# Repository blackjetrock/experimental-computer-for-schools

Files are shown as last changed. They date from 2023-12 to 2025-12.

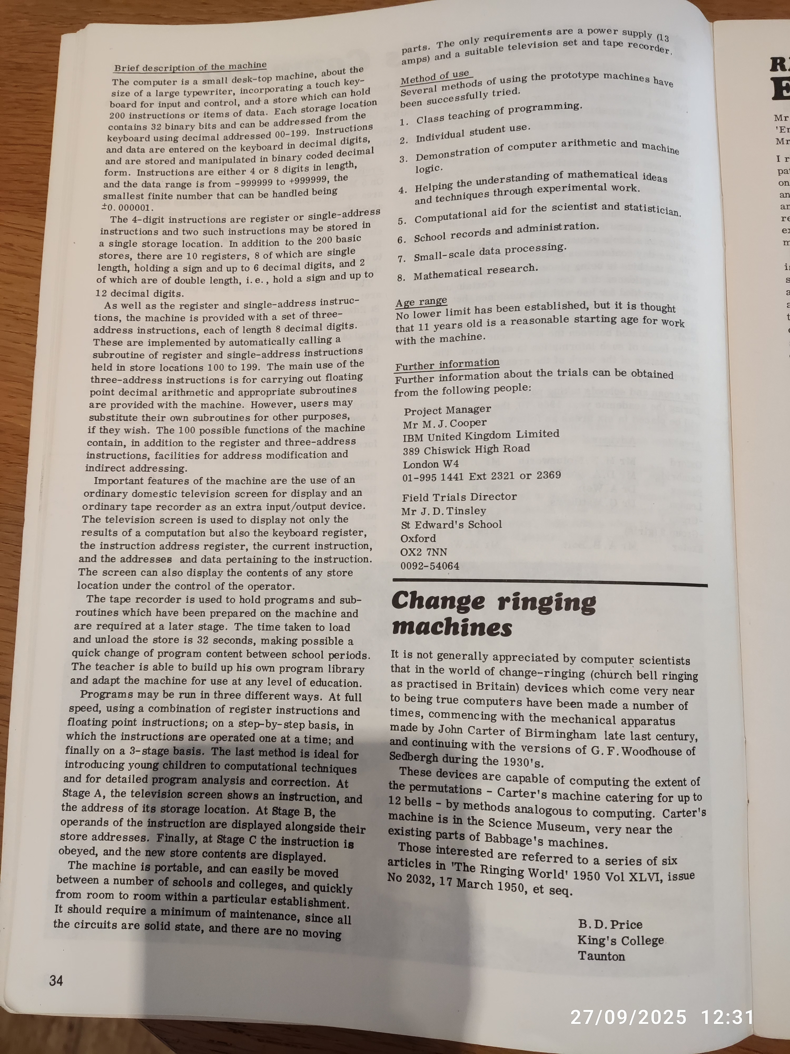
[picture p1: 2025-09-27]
Documentation/1000038514.jpg

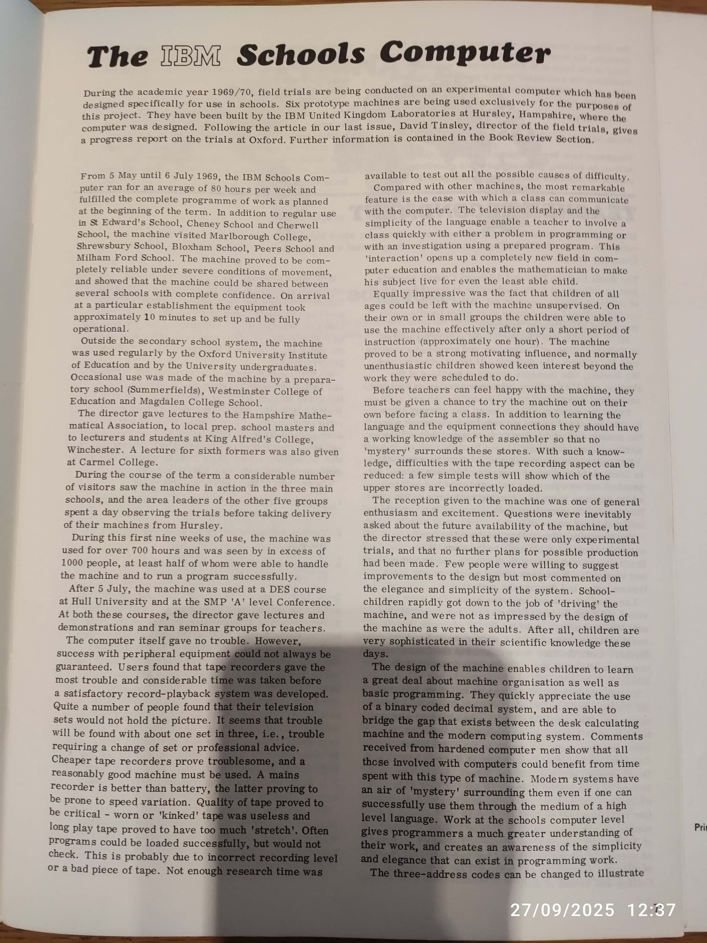
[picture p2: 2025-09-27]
Documentation/1000038515.jpg

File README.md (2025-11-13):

# IBM Experimental Computer for Schools

The schools computer project ran from 1966 to 1970 and was an experimental machine that was never sold, although several were made and were used in schools in the UK. One machine was used for ten years before it failed. It was designed to be used in schools to teach the basics of computer design and programming. The hardware was based on the same components that the IBM system 360 used. The computer was programmed in machine code, and unlike modern machines the machine code is BCD based, not binary. There are 'extracodes' in the system that are analogous to subroutines, these provided floating point arithmetic at the machine code level. The extracodes could be replaced with user code if desired, and provide a completely different set of functions.

As far as I an tell this machine was the first machine purpose built for education. there are lots of examples of computers being used to teach fundamentals of programming and computer architecture, but they are general purpose machines in educational situations, this is the earliest machine designed for the purpose I can find.

It also seems to be the first machine to use a domestic television as a display, and the first to use a tape recorder to store and load code.

This is a simulation of the machine. It can run code written for the original machine.

<h2>Update Nov 2025</h2>
More information about the School's Computer has been found. This is a large collection of documents, programs for the machine, and information about the machine. One item that is of particular interest is the original extracode for the machine. In fact, there are about four different extracodes for the machine. There is also a draft of a 'Second Course on the School's Computer', which provides more detailed information abou thow the machine works. This information has been kept (for over 50 years) by one of the pupils (thanks Tony) that used the machine when it was trialled. Thanks to him, the original extracode can be used by the replica.

<h1>USB</h1>
USB can be used to interact with the simulator. It just requires a Pico. You can run a simulator with just a Pico, the PCB isn't necessary. If you have a Pico W then you can access over WiFi as well.
A command line interface (CLI) is available on the USB connection, this requires a terminal emulator program such as minicom. Using the interface you can:

* Drive keys as if they came from the keyboard
* See a representation of the display.
* Run tests that check the simulation is running as required.
* Load programs from the document 'A First Course on the School's Computer'
* Run programs
* Examine the store
* Examine the machine state
* Load and store machine state from and to the SD card

<h1>Tests</h1>

There is a set of tests built in to the firmware that can be run to check th eoperation of the machine.
The tests are run using the '=' menu option on the USB CLI. They take quite a while to run and once finished the '@' menu option can be used to display the result. If a test is successful then 'Passed' is displayed. If it failed the 'Failed' is displayed, along with the expected and calculated results. It is possible to run a single test using the '[' command to load the test (after entering the test number with z nn ESC), then '+' to run it. The resut is displayed using '@'.

The tests are currently set up to test the standard extracode. This means the results are tailored to that extracode. As an instruction like 70202122 can perform any function, depending on th eextracode in 100..199 this will have to change.  I allowed the original extracode to be tested, though.

<h1>PCB</h1>

There is a PCB that has a Pico mounted on it. This photo shows the PCB with a Pico W attached. The simulator code can be built with or without WiFi support.

IMG_4442p1

This has a 0.96" OLED display that shows the same information as the original machine displayed on a domestic TV.



 There is an SD card for storage and a keyboard made from tactile switches, in the same layout as the original machines. The operation is very similar to the original, some differences have been made to key operations to enable use of the SD card. the original machines used audio cassettes for data storage.
 

 The Pico can be a PicoW, in which case a WiFi access point is generated.

<h1>Wifi Version</h1>
This version has a USB interface, and a Wifi interface (it generates a hot spot). The USB interface still works. The Wifi page shows the display and allows control from a web page. This version of the code runs on a Pico W and generates its own access point.

Screenshot from 2024-08-30 09-09-44

If building for a Pico W then use this command line:

<code>cmake -DPICO_BOARD=pico_w -DWIFI_SSID="Schools" -DWIFI_PASSWORD="password" ..</code>

to initialise the build directory in the 

<code>firmware/escw</code>

directory. Then 

<code>make</code>

as usual.
To build the non-Wifi version, 

<code>cmake ..</code>

in the 

<code>experimental_schools_computer/build</code>

directory and then make as usual.

<h1>Half Scale Replica</h1>

IMG_20240827_103823604_HDR

The half scale replica is constructed of similar materials to the original, and runs the same code as the small PCB version, with some modifications for the different display and keyboard. The display is a large LCD instead of a small OLED and a touch keyboard is used instead of tactile switches. The case is aluminium which has been powder coated, the keyboard surround is a 3D printed resin part. The original machine also used a plastic surround, this is probably because a metal surround would interfere with the touch keyboard. And, yes, that is the original machine next to the replica.

<h1>Assembler</h1>
I have created an assembler that assembles instructions expressed in the verbose comments seen in the documents available for this computer. 

<h1>Documents</h1>

<h2>A First Course on the Schools's Computer</h2>
This is a document that provided a course on programming the computer, there are only three known paper copies of this document (in two revisions), but it has been
copied and put together into a PDF document. It has several programs written for the machine, which are the only ones I know of from the time
when the machine was trialled. These programs almost exclusively use the extracodes for the programs, not the half-word basic instructions which must have been used to implement
the extracodes themselves in the store from address 100 to 199. 

<h2>A Draft Second Course on the School's Computer</h2>
This is a short typewritten document that is the beginning of a second course on the machine. It expains some of the instructions that weren't detailed in the first course. It appears that the School's Computer project was cancelled before this course could be completed.

<h2>Experimental Computer for Schools</h2>
Describes the hardware and code design of the machine. This is a technical description of the machine, and contains no program listings at all.

<h2>Flowcharts</h2>
This is a four page document that has flowcharts and programs for log<sub>b</sub>N and b<sup>L</sup>.
The programs use an extracode that isn't in the standard set, which is a square root instruction. The instruction also has a jump and the jump part is used in the programs without use of the square root operation. Together with the first course on the school's computer these are the only known programs for the computer from the time whenit was being develped and trialled.

<h2>Extracode</h2>
The extracode of the machine is sort of equivalent to the ROM in an 80's home computer, but there are significant differences. In its original form it provided some floating point instructions, and so compared to a ROM it provides a small number of features. Unlike a ROM, though, it was intended that people altered or even completely rewrote the extracode, and that did happen. Several different extracodes exist, for various reasons, they are listed below.
There is now framework for running extracode, so the original extracodes can be executed. It's not quite correct at the moment as the A,B and C stage keys step through the extracode instructions, on th eoriginal they stepped through the 'top level' three address instruction. 

<h3>Standard Floating Point</h3>
This is the extracode that provoides the instructions used in the 'First Course'. It provides simple floatoing point operations, these are listed in the 'Experimental Computer fo School's' document.

<h3>BASIC</h3>
this extracode is supplied in the form of a set of changes to be made to the standard extracode. It provides insrtuctiins that mirror a few BASIC commands. A BASIC program can be written (by hand, on paper) and then translated to extracdoe instructions, these can be entered into the school's computer and executed. There are some examples of this isn the documents.

<h3>Pseudo Random Number Generator</h3>

<h3>Square Root</h3>
This extracode provides a square root instruction. It replaced one of the standard extracodes and was used for any program that needed a square root. It is mentioned in some of the first documents I found, and a listing is in the latest documents.

<h3>Noughts and Crosses</h3>
This game was written by Tony Malins around 1970 and was such a large program that it used the extracode space as well as the user space.

<h1>References</h1>

The thread on 'retrocomputingforum.com' where Tony presents his documents and programs:
https://retrocomputingforum.com/t/rare-ibm-schools-computer-1969/5209/51

A photo of the schools computer in a classroom in the 60s:
https://www.stedwardsarchives.org/PDFViewer/web/viewer.html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

https://www.stedwardsarchives.org/PDFViewer/web/viewer.html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

https://ibmhursleymuseum.info/hardware-data-detail.asp?id1=140

https://news.ycombinator.com/item?id=36112633

https://www.stedwardsarchives.org/PDFViewer/web/viewer.html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

https://www.stedwardsarchives.org/PDFViewer/web/viewer.html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

https://www.stedwardsarchives.org/PDFViewer/web/viewer.html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

https://www.stedwardsarchives.org/PDFViewer/web/viewer.html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

https://www.stedwardsoxford.org/obituary/david-tinsley/

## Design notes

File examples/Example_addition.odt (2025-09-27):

Experimental Computer for Schools

Example

This example adds two numbers by loading the store with the values and then using a ‘Keyboard Reset’ to enter an instruction that adds the contents of two locations in the store, putting the result in a third location.

With the ESC replica on:

Press ‘Normal reset’

Press ‘1’

Press ‘2’

Press ‘Load addr’

Press ‘4’

Press ‘5’

Press ‘point’

Press ‘3’

Press ‘Load store’

Press ‘Incr addr’

Press ‘1’

Press ‘3’

Press ‘point’

Press ‘9’

Press ‘Load store’

The two values to add are now in store locations 11 and 12.

Now, enter and run the addition instruction:

Press ‘Ki Reset’

Type the number: ‘70101112’

This is the instruction code.

Press ‘A’

The first stage of the instruction is processed (store addresses are shown)

Press ‘B’

The second stage of the instruction has been processed. The contents of the store locations are shown. These are the two values that will be added.

Press ‘C’

The instruction is processed to completion. The sum can be seen as the contents of store location 10:

Press ‘1’

Press ‘0’

Press ‘Load addr’

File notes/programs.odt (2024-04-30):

Experimental School’s Computer

Programs

This document is a collection of programs for the experimental school’s computer from around 1970. There are not very many programs known, these all come from the first course on the school’s computer.

A Program to Compute the Surface Area and Volume of a Sphere.

Address | Contents | Comments
0 | | Spare
1 | | Spare
2 | r
3 | a
4 | b
5 | 3.14159
6 | 4
7 | 3
8 | | Spare
9 | | Spare
10 | 7802 0507 | Input r; display 3.14159 and 3
11 | 7203 0202 | a ← r x r
12 | 7203 0305 | a ← a x 3.14159
13 | 7203 0306 | a ← a x 4
14 | 7204 0302 | b ← a x r
15 | 7304 0407 | b ← b ÷ 3
16 | 7902 0304 | Display r, a and b
17
18
19
20

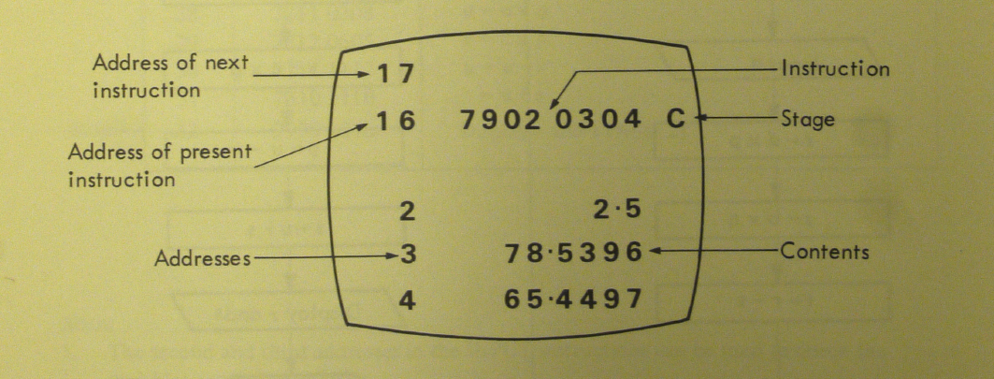
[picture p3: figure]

SOLUTION OF TWO LINEAR SIMULTANEOUS EQUATIONS

Address | Contents | Comments
0 | | Spare
1 | | Spare
2 | | Spare
3 | a
4 | b
5 | p
6 | c
7 | d
8 | q
9 | r
10 | s
11 | u
12 | v
13
14
15 | 7803 0303 | Input a
16 | 7804 0303 | Input b
17 | 7805 0403 | Input p
18 | 7806 0504 | Input c
19 | 7807 0605 | Input d
20 | 7808 0706 | Input q
21 | 7209 0705 | r ← d x p
22 | 7210 0408 | s ← b x q
23 | 7109 0910 | r ← r - s
24 | 7210 0307 | s ← a x d
25 | 7211 0406 | u ← s - u
26 | 7110 1011 | s ← s – u
27 | 7309 0910 | r ← r ÷ s
28 | 7211 0308 | u ←a x q
29 | 7212 0605 | v ← c x p
30 | 7111 1112 | u ← u - v
31 | 7310 1110 | s ← u ÷ s
32 | 7909 1010 | Display r and s; stop

Experimental School’s Computer Programs

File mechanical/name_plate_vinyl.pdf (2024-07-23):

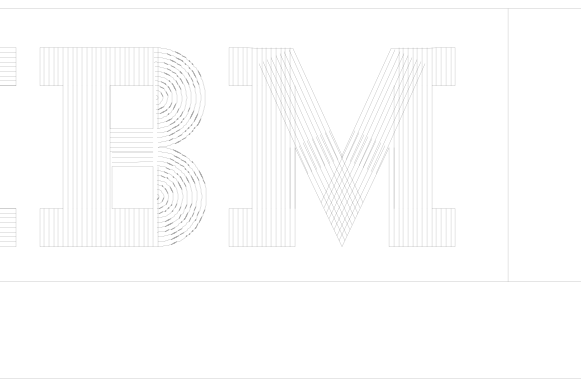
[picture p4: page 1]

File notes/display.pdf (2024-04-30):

Experimental School’s Computer Display Notes

Experimental Schools Computer Display

The TV display on the experimental school’s computer shows various pieces of information, at various times during the execution of programs and instructions. The documentation of the machine, which is limited, has some examples of the display. This document is an attempt to list these displays and the information they contain, link that to the events that caused the display and hopefully build up the rules that the machine uses to put information onto the display. This can then be coded in the simulation to give the user a display that is as useful as the original and also hopefully close to the original displays.

The display is 15 characters wide by six lines.

Experimental School’s Computer Display Notes

## Sequence 1

After resetting

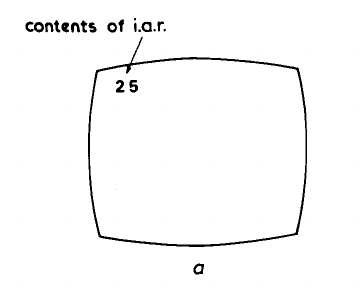
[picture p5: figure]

After keying in address

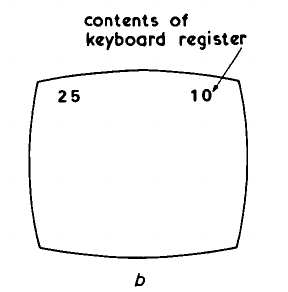
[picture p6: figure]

Experimental School’s Computer Display Notes

Experimental School’s Computer Display Notes

After touching LOAD ADDR key

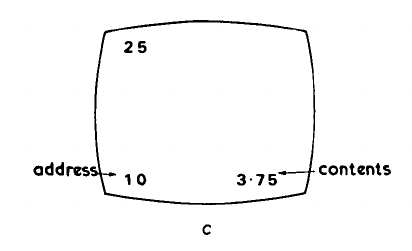
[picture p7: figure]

After keying in number to be loaded

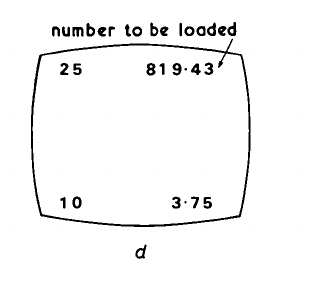
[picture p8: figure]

After touching LOAD STORE key

Experimental School’s Computer Display Notes

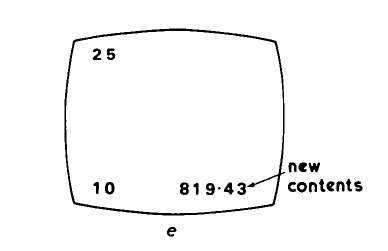
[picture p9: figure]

## Sequence 2

After keying in address of first instruction in program

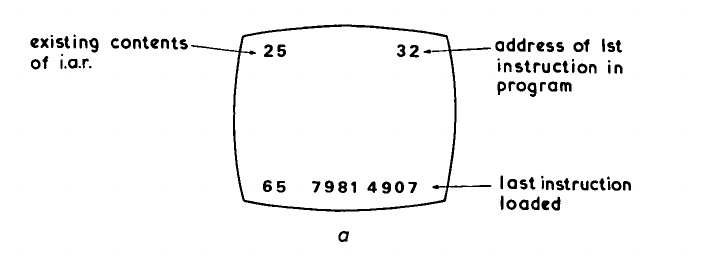
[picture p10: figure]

After touching LOAD IAR key

Experimental School’s Computer Display Notes

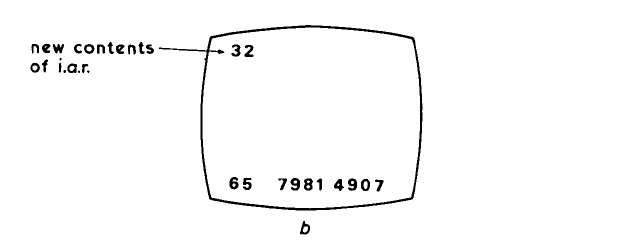
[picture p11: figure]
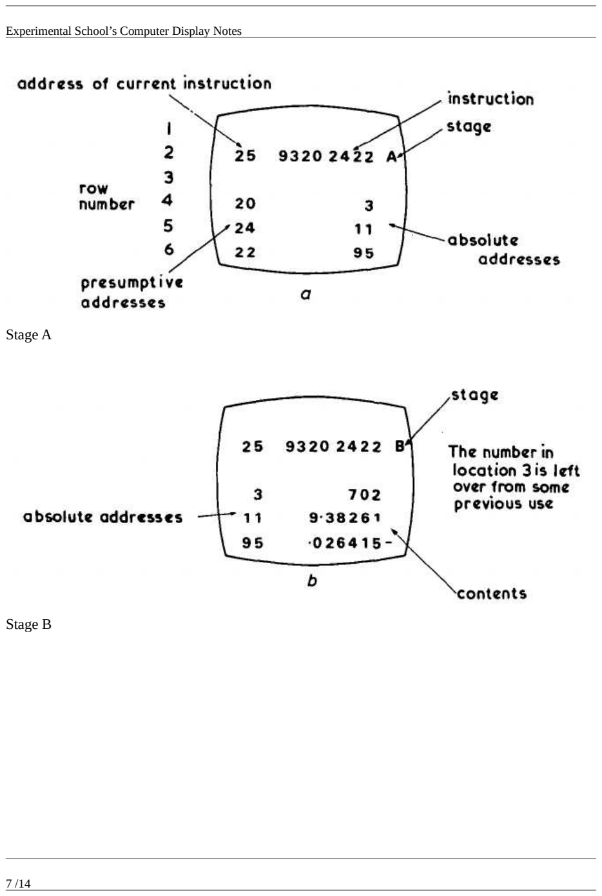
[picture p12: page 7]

Experimental School’s Computer Display Notes

Stage A

Stage B

Experimental School’s Computer Display Notes

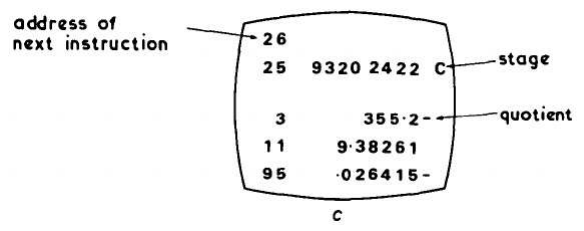
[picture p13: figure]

Stage C

Experimental School’s Computer Display Notes

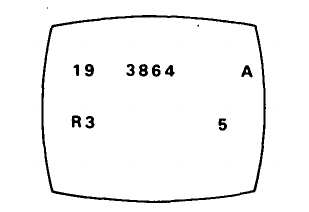
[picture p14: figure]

Single-address instruction with relative addressing

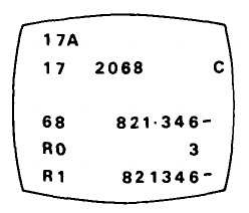
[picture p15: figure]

Single-address READ STORE instruction

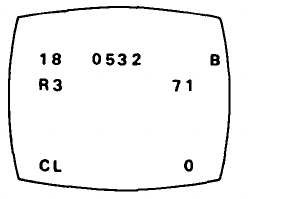
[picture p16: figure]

Experimental School’s Computer Display Notes

TEST instruction

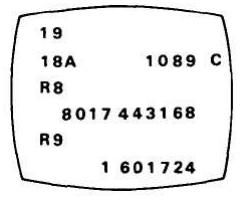
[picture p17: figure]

Adding contents of two double-length registers

Experimental School’s Computer Display Notes

From these screen layouts it appears that the top two lines of the display are in a fixed format, with the IAR, the address of the next instruction and the keyboard register contents displayed as the registers have values entered in them. There is also a display of the IAR flag that shows an ‘A’ when the instruction in the lower 4 digits is being referenced. The instruction processing stage (A,B, or C0 is also displayed.

The lower 4 lines, though, seem to be more free-form, with data displayed as instructions are processed. These lines will have data displayed as instructions are processed.

The character set is quite complete, the full ASCII set is available to the simulation, so that will be used. A small OLED display on the PCB is used to recreate the TV display, there is also a Usb CLI that has moire extensive displays, for instance the entire store can be displayed.

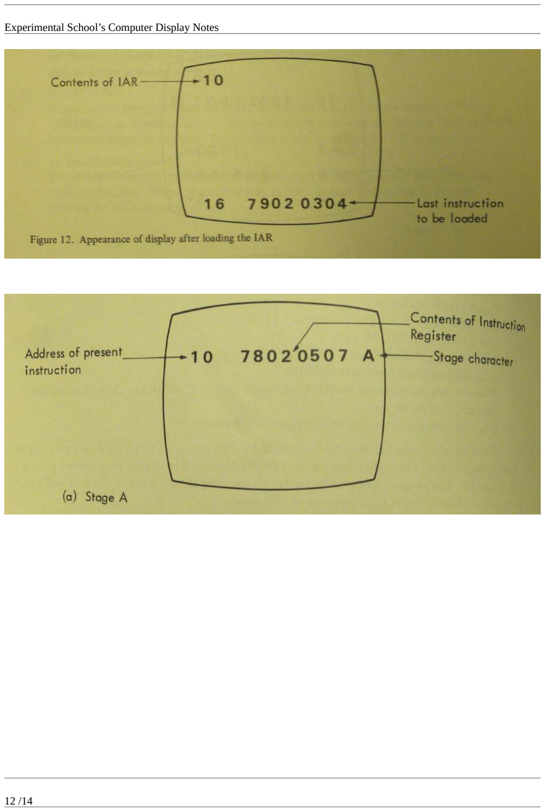
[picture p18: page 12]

Experimental School’s Computer Display Notes

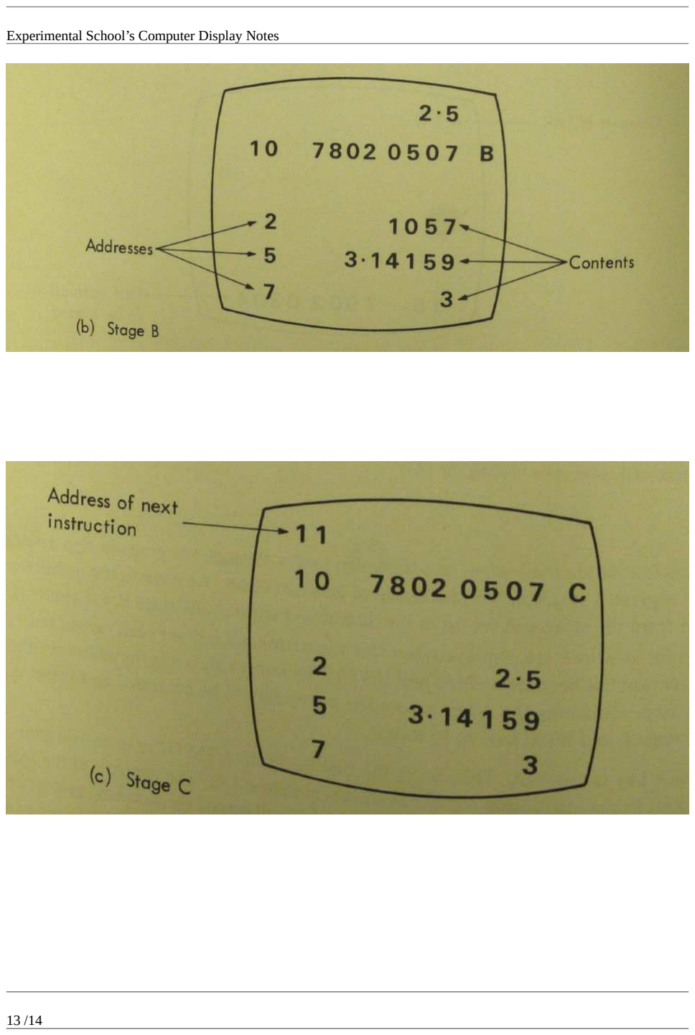
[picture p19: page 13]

Experimental School’s Computer Display Notes

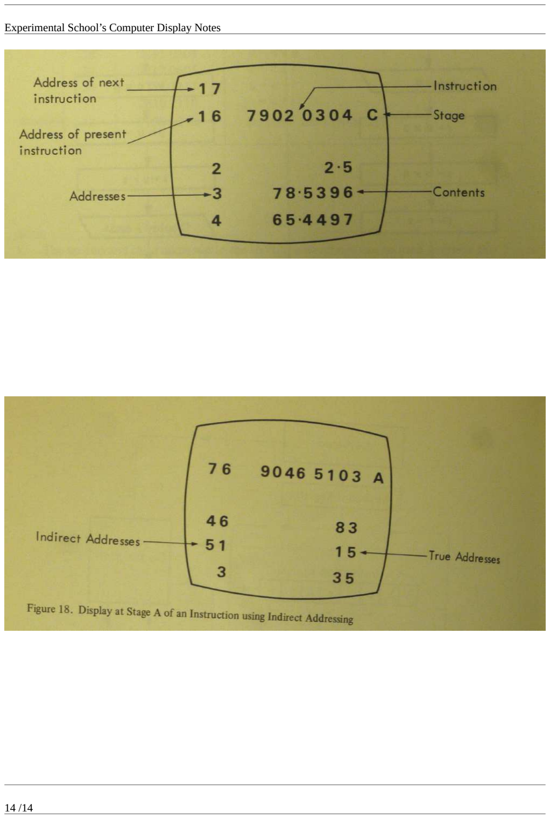
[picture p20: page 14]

Experimental School’s Computer Display Notes

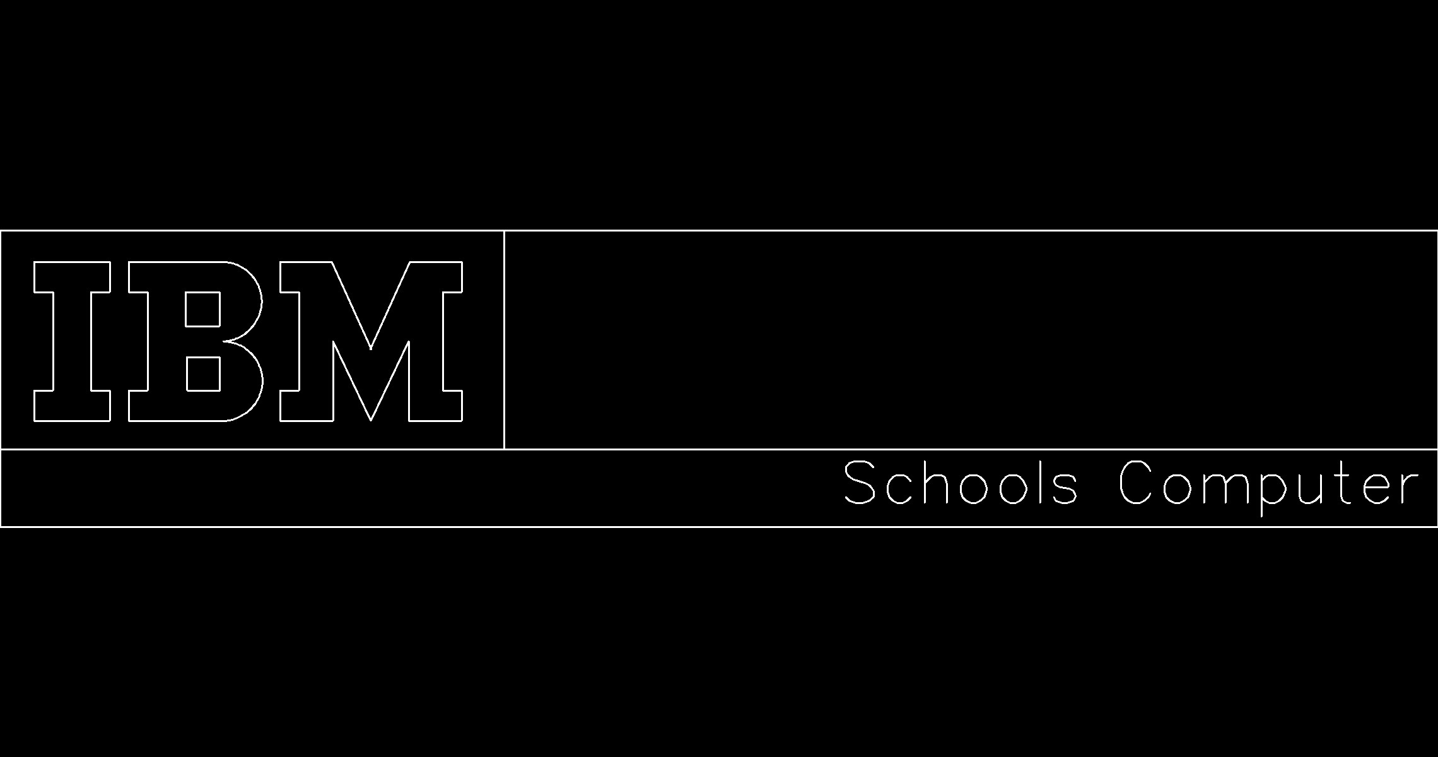
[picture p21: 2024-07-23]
mechanical/labels/name_plate_vinyl_base_file.png

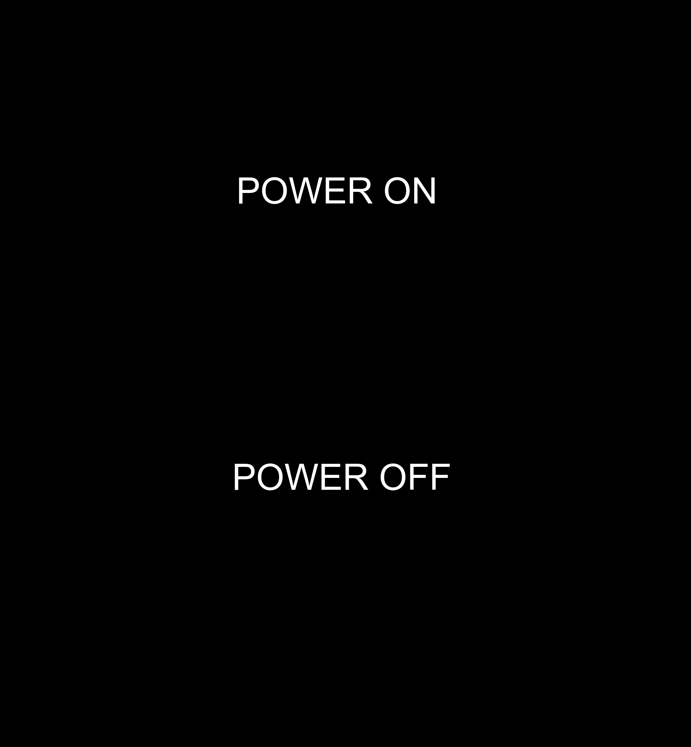
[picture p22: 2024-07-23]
mechanical/labels/power_label_1.png

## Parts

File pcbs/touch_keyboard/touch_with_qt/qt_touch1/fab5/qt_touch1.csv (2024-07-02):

Id | Designator | Package | Quantity | Designation | Supplier and ref
1 | C21,C20,C19,C18,C17 | C_1206_3216Metric_Pad1.33x1.80mm_HandSolder | 5 | 25uF
2 | C16 | C_1206_3216Metric_Pad1.33x1.80mm_HandSolder | 1 | 100uF
3 | U4,U3,U2 | SOIC-16W_7.5x10.3mm_P1.27mm | 3 | cd40109
4 | JP2 | SolderJumper-2_P1.3mm_Open_TrianglePad1.0x1.5mm | 1 | DBG_DATA
5 | JP1 | SolderJumper-2_P1.3mm_Open_TrianglePad1.0x1.5mm | 1 | DBG_LED
6 | R22 | R_0805_2012Metric_Pad1.20x1.40mm_HandSolder | 1 | 0R
7 | D2 | LED_0805_2012Metric_Pad1.15x1.40mm_HandSolder | 1 | ss36
8 | D1 | LED_0805_2012Metric_Pad1.15x1.40mm_HandSolder | 1 | LED
9 | J1 | PinSocket_1x12_P2.54mm_Vertical_SMD_Pin1Left | 1 | Conn_01x12_Female
10 | C15,C14,C13,C12,C5,C4,C3 | C_0805_2012Metric_Pad1.18x1.45mm_HandSolder | 7 | 100nF
11 | C11,C10,C9,C8,C7,C6 | C_0805_2012Metric_Pad1.18x1.45mm_HandSolder | 6 | 4n7
12 | C2,C1 | C_0805_2012Metric_Pad1.18x1.45mm_HandSolder | 2 | 20pF
13 | Y1 | Crystal_SMD_HC49-SD_HandSoldering | 1 | 16MHz
14 | U1 | LQFP-44_10x10mm_P0.8mm | 1 | QT1481
15 | TP28 | qt_touch_12_x_12 | 1 | 0
16 | TP27 | qt_touch_12_x_12 | 1 | 6
17 | TP26 | qt_touch_12_x_12 | 1 | DOT
18 | TP25 | qt_touch_12_x_12 | 1 | 9
19 | TP24 | qt_touch_12_x_12 | 1 | 3
20 | TP23 | qt_touch_12_x_12 | 1 | 5
21 | TP22 | qt_touch_12_x_12 | 1 | MINUS
22 | TP21 | qt_touch_12_x_12 | 1 | 8
23 | TP20 | qt_touch_12_x_12 | 1 | CHECK
24 | TP19 | qt_touch_12_x_12 | 1 | 2
25 | TP18 | qt_touch_12_x_12 | 1 | 4
26 | TP17 | qt_touch_12_x_12 | 1 | DUMP
27 | TP16 | qt_touch_12_x_12 | 1 | CLEAR
28 | TP15 | qt_touch_12_x_12 | 1 | RELOAD
29 | TP14 | qt_touch_12_x_12 | 1 | 1
30 | TP13 | qt_touch_12_x_12 | 1 | 7
31 | TP12 | qt_touch_12_x_12 | 1 | STOP
32 | TP11 | qt_touch_12_x_12 | 1 | INCR ADDR
33 | TP10 | qt_touch_12_x_12 | 1 | LOAD ADDR
34 | TP9 | qt_touch_12_x_12 | 1 | C
35 | TP8 | qt_touch_12_x_12 | 1 | RUN
36 | TP7 | qt_touch_12_x_12 | 1 | NORM RESET
37 | TP6 | qt_touch_12_x_12 | 1 | LOAD STORE
38 | TP5 | qt_touch_12_x_12 | 1 | KI RESET
39 | TP4 | qt_touch_12_x_12 | 1 | B
40 | TP3 | qt_touch_12_x_12 | 1 | DECR ADDR
41 | TP2 | qt_touch_12_x_12 | 1 | LOAD IAR
42 | TP1 | qt_touch_12_x_12 | 1 | A
43 | R21,R20,R19,R18,R17,R16,R15,R14,R13,R12,R11,R10,R8,R7 | R_0805_2012Metric_Pad1.20x1.40mm_HandSolder | 14 | 1k
44 | R9,R6,R5,R4,R3 | R_0805_2012Metric_Pad1.20x1.40mm_HandSolder | 5 | 470k
45 | R2 | R_0805_2012Metric_Pad1.20x1.40mm_HandSolder | 1 | 407k
46 | R1 | R_0805_2012Metric_Pad1.20x1.40mm_HandSolder | 1 | 4k7

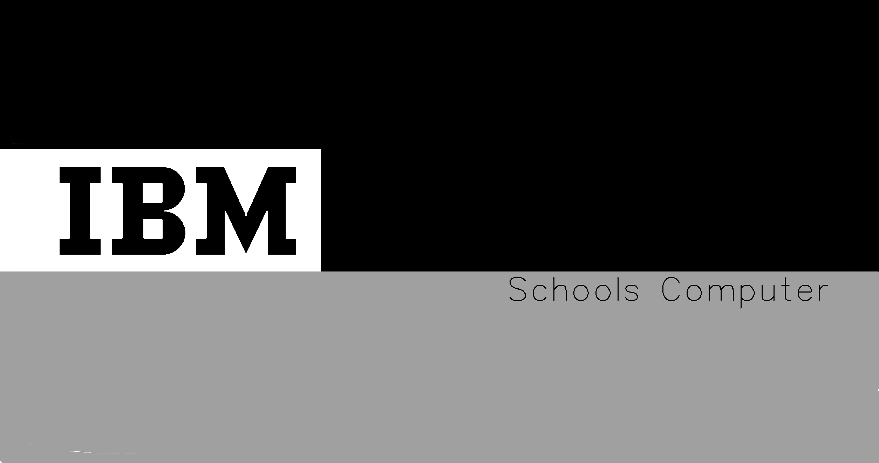
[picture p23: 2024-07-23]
mechanical/labels/name_plate_vinyl_base_file_order_file.png

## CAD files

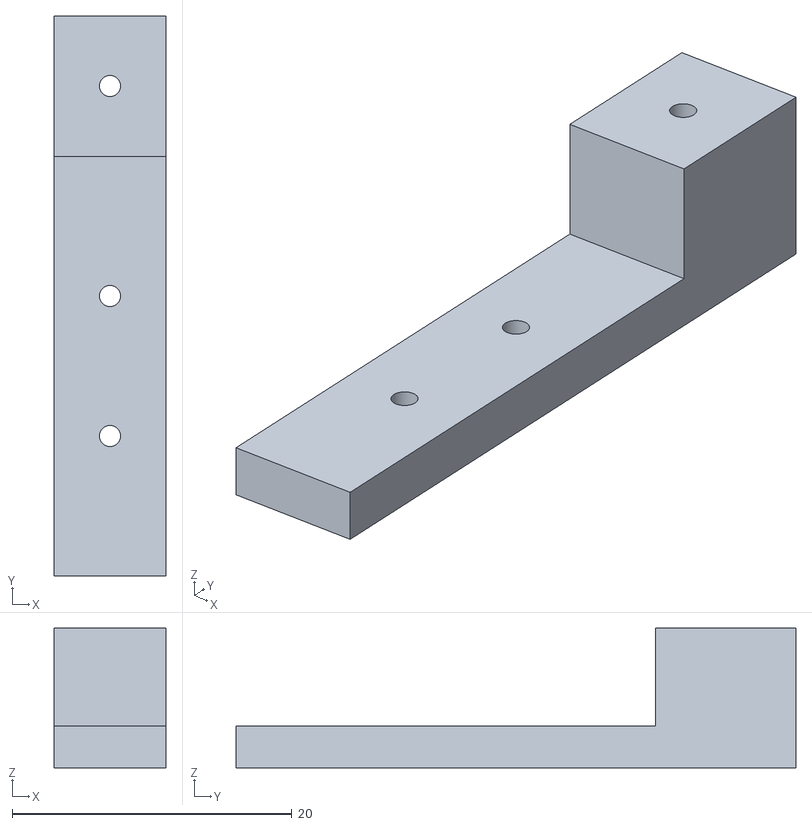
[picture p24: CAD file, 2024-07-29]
mechanical/3d_models/tv_spacer_straight.stl
8.00 x 40.0 x 10.0

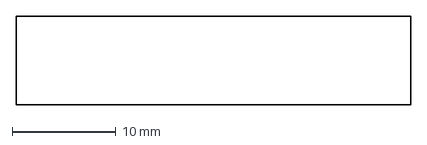
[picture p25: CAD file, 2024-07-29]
mechanical/front_panel_62mm_name_recess_only_1_5mm.dxf
38.0 x 8.50 mm

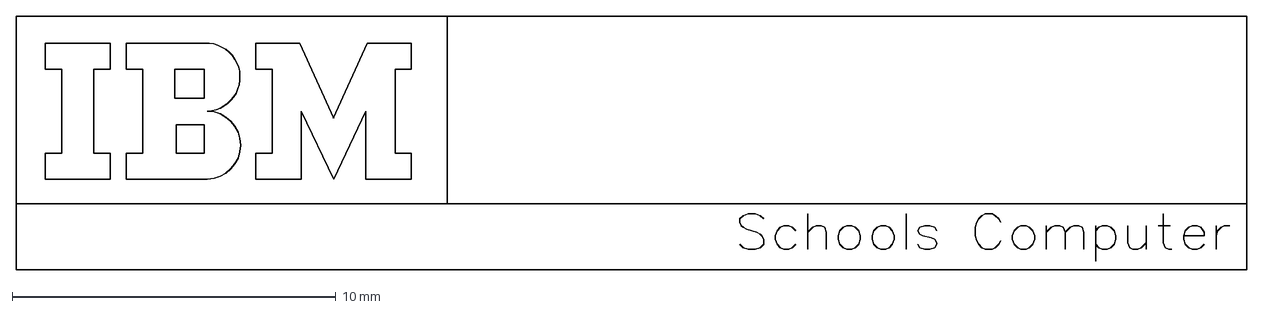
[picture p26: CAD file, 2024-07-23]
mechanical/labels/vinyl_base.dxf
38.0 x 7.83 mm

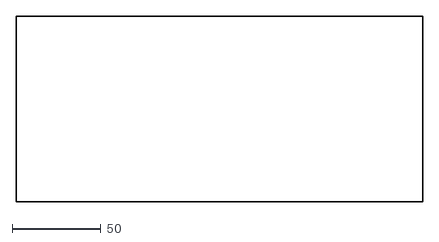
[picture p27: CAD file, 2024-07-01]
pcbs/touch_keyboard/touch_with_qt/overlay1/fab1/overlay1-Edge_Cuts.dxf
229.1 x 104.6

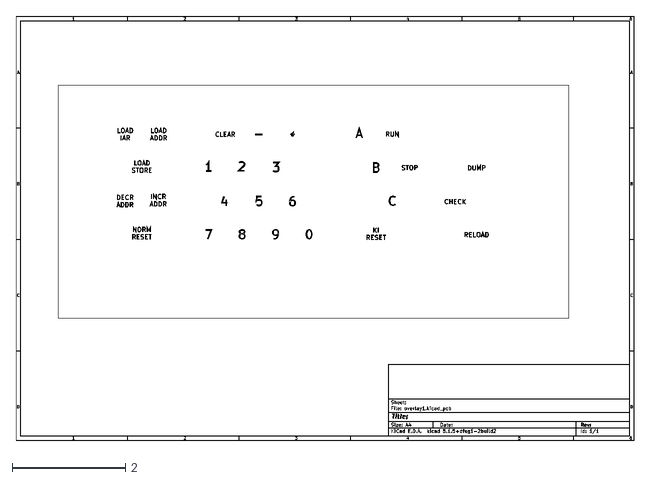
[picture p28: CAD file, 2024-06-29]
pcbs/touch_keyboard/touch_with_qt/overlay1/svg_fr/overlay1-brd.dxf
10.9 x 7.49

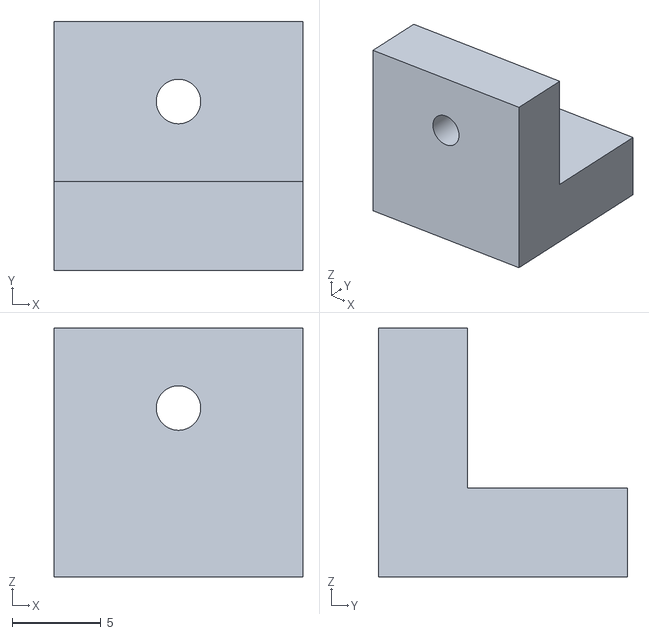
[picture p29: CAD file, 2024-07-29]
mechanical/3d_models/cased_desktop_angle_bracket.stl
14.0 x 14.0 x 14.0

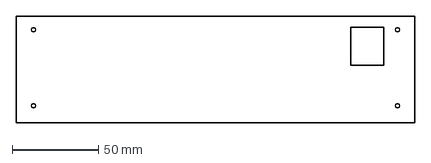
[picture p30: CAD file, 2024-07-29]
mechanical/front_panel_62mm_no_name_cutout.dxf
231.0 x 62.0 mm

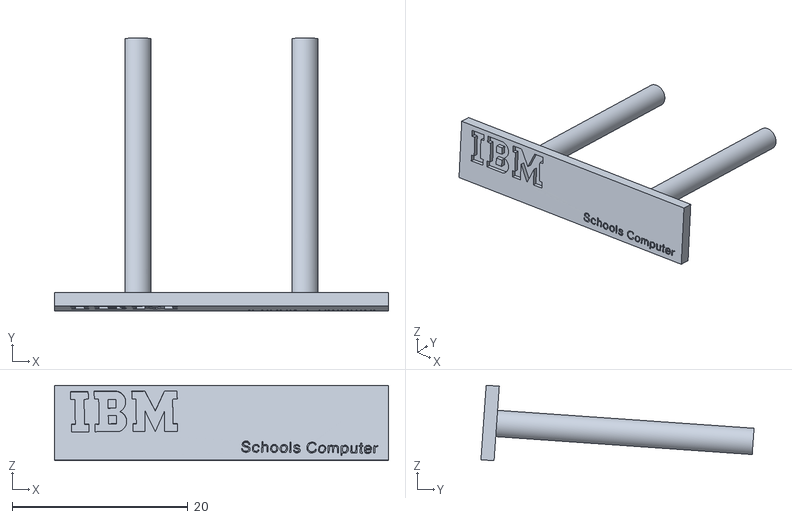
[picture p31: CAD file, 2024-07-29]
mechanical/3d_models/cased_desktop_name_plate.stl
38.0 x 31.1 x 8.58

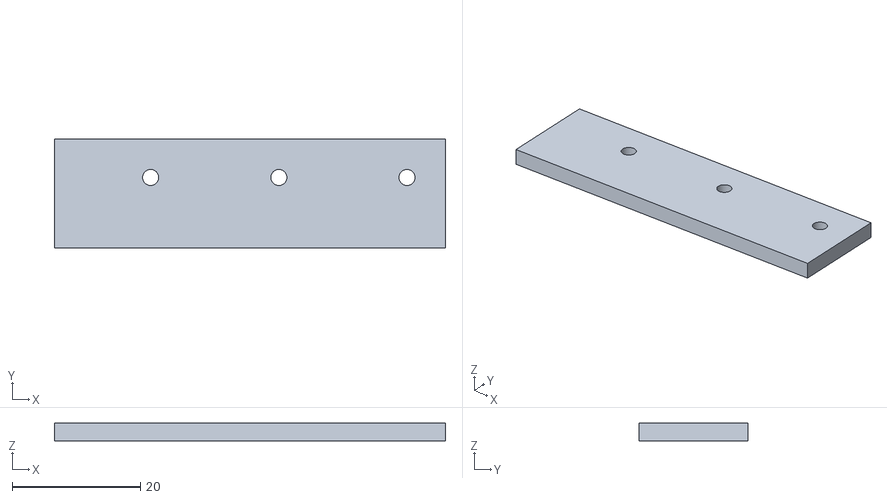
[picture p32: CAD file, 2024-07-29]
mechanical/3d_models/cased_desktop_kb_pcb_holder.stl
61.0 x 17.0 x 2.80

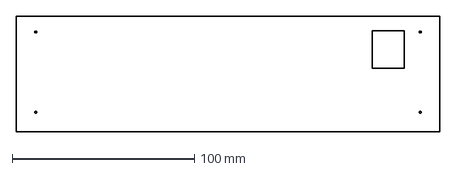
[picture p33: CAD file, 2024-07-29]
mechanical/front_panel_62mm_no_name_cutout_1_5mm.dxf
232.5 x 63.5 mm

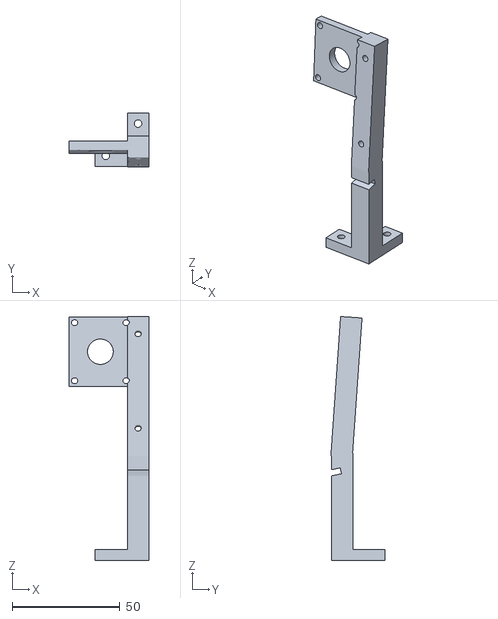
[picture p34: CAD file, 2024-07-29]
mechanical/3d_models/cased_desktop_right_support.stl
37.0 x 25.3 x 113.4

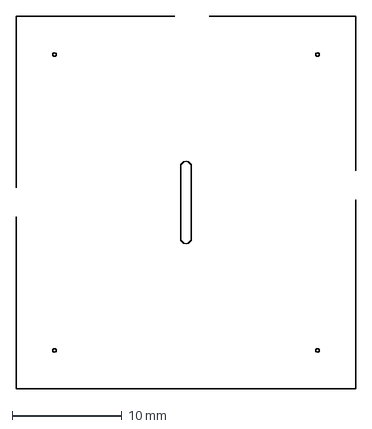
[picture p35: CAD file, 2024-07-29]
mechanical/switch_plate_cutout_2_0mm_tool.dxf
31.0 x 34.0 mm

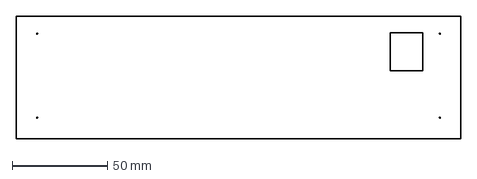
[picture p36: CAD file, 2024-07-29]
mechanical/front_panel_62mm_no_name_cutout_2_0mm.dxf
233.0 x 64.0 mm

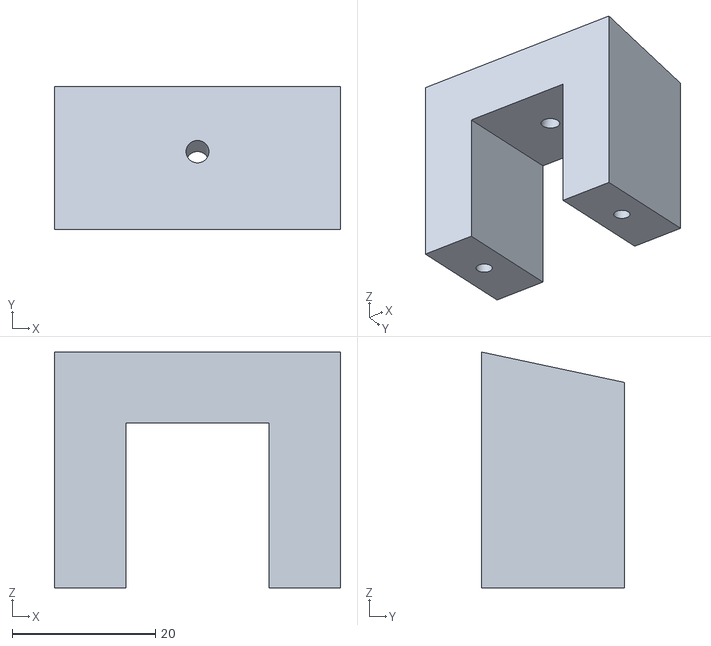
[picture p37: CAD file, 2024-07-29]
mechanical/3d_models/kb_support.stl
40.0 x 20.0 x 33.0

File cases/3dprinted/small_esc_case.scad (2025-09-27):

module small_esc_pcb()
{
  rotate([0,0,90])
    {
      translate([0, 0, 0])
        {
          scale([1,1,1])
            {
              //linear_extrude(height = 1, center = true, convexity = 10,twist=0)
              import("small_esc.stl", center=true);
            }
          // Cylindrical spike that can be used to check poisitions of 
          // components on the PCB
          
        }
    }
}



hull($fn = 50)
{
    
    translate([-20, -40, 30])
    {
        rotate([0, 30, 0])
        {
   cube([30, 25, 20], center=true);
        }   
    }
small_esc_pcb();
}

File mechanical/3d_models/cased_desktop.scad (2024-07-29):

// Case for desktop ESC
//
//

$fn = 200;

show_pcb             = 0;
show_top             = 0;
show_kb_part         = 0;
show_kb_part_proj    = 0;
show_left_support    = 0;
show_right_support   = 1;
show_front_panel     = 0;
show_base            = 0;
show_kb_pcb_holder   = 0;
show_angle_bracket   = 0;
show_name_plate      = 0;
show_lh_ruler        = 0;
show_rh_ruler        = 0;

// Angle of back part of kb plate
kb_bk_angle= 4;
front_panel_angle = 4;

// Extra 1mm all round for wall to hold PCBs
len_x = 229+2;
len_y = 104.5+2;
kb_plate_x = len_x;
kb_plate_y = len_y;  // Extra 1mm all round

kb_fr_y = 1;
kb_fr_z = 41.19/2;

kb_bk_x = len_x;
kb_bk_y = 1;
kb_bk_z = 20.76/2;

th=1.5;
wall_z = 2.8;

kb_panel_rad = 2.5;

front_panel_x = len_x - th;
front_panel_y = 68.5-kb_bk_z;

case_top_x = len_x+2*th;
case_top_y = 184; 

case_y = 291;
case_z = 110+th;

pcb_x = 229;
pcb_y = 104.5;
pcb_th = 1.6;

module kb_pcb()
{
     cube([pcb_x, pcb_y, pcb_th], center=true);
     import("overlay1-F_SilkS.dxf");
}

// Put a lip at one end of the PCB sandwich and a plate at the other end
// that allows a retaining bracket to be mounted

bracket_y = 10;

// Make a sliced rounded tube that can be used for filleting and radiusing corners.

module part_hollow_tube(len, rs, rb, angle1, angle2)
{
     translate([0, 0, 0])
	  rotate([0, 0, 0])
	  difference()
     {
	  rotate([0, 90, 0])
	       cylinder(r=rb, h=len, center=true);
	  rotate([0, 90, 0])
	       cylinder(r=rs, h=len+0.1, center=true);

	  translate([-len/2-0.1, -(rb+0.1), -(rb+0.1)])
	       cube([len+0.2, rb+0.11, rb+0.11]);
	  translate([-len/2-0.1, 0, -(rb+0.1)])
	       cube([len+0.2, rb+0.11, rb+0.11]);
	  translate([-len/2-0.1, 0, 0])
	       cube([len+0.2, rb+0.11, rb+0.11]);
         
	  rotate([angle1, 0, 0])
	       translate([-len/2-0.1, 0, 0])
	       cube([len+0.2, rb+0.1, rb+0.1]);
     }
}


module retain_a()
{   
// Wall around the PCBs
     cube([len_x, len_y, wall_z], center=true);

// Lip to hold one side
     translate([0, -len_y/2+3/2, -wall_z/2-1])
	  cube([len_x, 4, 2], center=true);
    
//Top bracket mount  
     translate([0, len_y/2+bracket_y/2, 0])
	  cube([len_x, bracket_y, wall_z], center=true);
}

module key_plate_1()
{
     translate([-len_x/2+1, -kb_plate_y/2+1, 0])
	  linear_extrude(height = th, center = true, convexity = 10,twist=0)
	  import("../kb_holes.dxf");


//cylinder(d=th, h=kb_bk_x, center=true);

//translate([0, kb_plate_y/2, 0])
//rotate([0, 90, 0])
//cylinder(d=th, h=kb_bk_x, center=true);

//translate([1, kb_plate_y/2-th*2/3, th])
//rotate([0, 90, 0])
//cylinder(d=th, h=kb_bk_x, center=true);
   
    
// Put a wall round the edge to hold the two PCBs
     translate([0, 0, -th/2-wall_z/2])
	  difference()
     {
	  retain_a();

// Take centre of cube away to leave a wall around the PCBs
	  cube([len_x-2, len_y-2, wall_z+0.1], center=true);
     
	  for(x=[-len_x/2+20:20:len_x/2-20])
	       translate([x, len_y/2+bracket_y/2, 0])   
		    cylinder(d=2.5, h=6, center=true);
     }

   
}

// Bar that holds keyboard pcbs in the frame

module holder_a()
{   
     translate([0, len_y/2+bracket_y/2, 0])
	  cube([len_x-170, bracket_y*2.0, wall_z], center=true);
}

module kb_pcb_holder()
{
     translate([0, -bracket_y/2, -th/2-wall_z/2])
	  difference()
     {
	  holder_a();

	  cube([len_x-2, len_y-4, wall_z+0.1], center=true);
     
	  for(x=[-len_x/2+20:20:len_x/2-20])
	       translate([x, len_y/2+bracket_y/2+4, 0])   
		    cylinder(d=2.5, h=6, center=true);
     }
   
}


module k_bevel()
{
     kh = [
	  [0, 0, 0], 
	  [29.986, -.4977, 0], 
	  [29.986+15, -.4977, 0], 
	  [29.986+2*15, -.4977, 0], 
	  [29.986+3*15, -.4977, 0], 
	  [29.986+5*15, -.4977, 0], 
	  [29.986+8*15, -.4977, 0],
	  [0, 29.4979, 0], 
	  [29.986, 29.4979, 0], 
	  [29.986+1*15, 29.4979, 0], 
	  [29.986+2*15, 29.4979, 0], 
	  [29.986+5*15, 29.4979, 0], 
	  [29.986+6*15, 29.4979, 0], 
	  [29.986+8*15, 29.4979, 0],
	  [-7.513+0*15, 14.5036, 0], 
	  [-7.513+1*15, 14.5036, 0], 
	  [-7.513+3*15, 14.5036, 0], 
	  [-7.513+4*15, 14.5036, 0], 
	  [-7.513+5*15, 14.5036, 0], 
	  [-7.513+8*15, 14.5036, 0], 
	  [-7.513+10*15-2, 14.5036, 0], 
	  [-7.513+0*15, 14.5036+29.9801, 0], 
	  [-7.513+1*15, 14.5036+29.9801, 0], 
	  [-7.513+3*15, 14.5036+29.9801, 0], 
	  [-7.513+4*15, 14.5036+29.9801, 0], 
	  [-7.513+5*15, 14.5036+29.9801, 0], 
	  [-7.513+7*15, 14.5036+29.9801, 0], 
	  [-7.513+8*15, 14.5036+29.9801, 0], 
	  ];
    
     translate([-kb_plate_x/2+37.5206+1, -kb_plate_y/2+37.9969+1, -th/2+th/2])    
	  for( a = kh) for( b = a) {
		    translate(a) 
			 cylinder(r1=6.252, r2=6.252+1, h=th+0.1, center=true);
	       }
}


module key_plate()
{
     difference()
     {
	  key_plate_1();
	  k_bevel();
       
     }
}

fr_block_x = 10;
fr_block_y = 10;
fr_block_z = 5;

//translate([0, 0, kb_fr_z/2])
//rotate([0, 90, 0])
//%cylinder(d=th, h=kb_bk_x, center=true);
module fr()
{
     translate([0, 0, kb_fr_z/2])
	  
	  rotate([12, 0, 0])
	  
	  translate([0, kb_plate_y/2, 0])
	  key_plate();

     sh2 = 2;
     translate([0, kb_plate_y*cos(12), kb_fr_z/2+kb_plate_y*sin(12)])
	  rotate([-kb_bk_angle, 0, 0])    
	  translate([0, 0, kb_bk_z/2-sh2/2])    
	  cube([len_x, th, kb_bk_z+sh2], center=true);
}

module kb_part()
{
 
     sh = 2.5;
    
// front vertical surface   
     translate([0, 0, sh/2])
	  cube([len_x, th, kb_fr_z+sh], center=true);

// Add some tabs for fixing the front of the part to the base
     for(off=[-100:50:100])
     {
	  translate([off, fr_block_y/2, -kb_fr_z/2+fr_block_z/2+th])
	       difference()
	  {
	       cube([fr_block_x, fr_block_y, fr_block_z], center=true);
	       cylinder(d=2.5, h=fr_block_z*1.2, center=true);
	  }
     }
    
     fr();
     
}

module top_side(off_y)
{

     translate([off_y, 0, -kb_fr_z/2])
	  rotate([0, -90, 0])
	  rotate([0, 0, 0])
	  linear_extrude(1) 
     {
	  polygon(
	       points = 
	       [
		    [0, -th], 
		    [20.5+th, -th], 
		    [42.5+th, 101], 
		    [115.08+th, 106.67], 
		    [104.5+th, 291], 
		    [0, 291], 
		    ]

		    
	       );
     }
 
}

module top_top()
{
     translate([0, (case_y-case_top_y)+case_top_y/2, case_z-kb_fr_z/2])
	  rotate([-3, 0, 0])
	  cube([case_top_x, case_top_y, th], center=true);
}

module top()
{
     top_top();
     top_side(-len_x/2-th/2);
     top_side( len_x/2+th/2);
}

module f_panel()
{
     linear_extrude(height = 1.5, convexity = 20, twist=0)
    
	  //import("../test.dxf");
	  import("../front_panel2.dxf");
     //import("../kb_holes.dxf");
    
}

module front_panel()
{
     translate([-115.5, kb_plate_y*cos(12)+0.7, kb_bk_z*2+kb_fr_z/2+kb_plate_y*sin(12)-kb_bk_z])
	  translate([0, 0, -kb_fr_z/2])
	  rotate([-front_panel_angle+90, 0, 0])
	  translate([0, front_panel_y/2-18.9, 0])
     {
	  f_panel();
	  translate([10, 10, 0])
	       cylinder(d=3, h=40, center=true);
	  translate([231-10, 10, 0])
	       cylinder(d=3, h=40, center=true);
	  translate([10, 64-10, 0])
	       cylinder(d=3, h=40, center=true);
	  translate([231-10, 64-10, 0])
	       cylinder(d=3, h=40, center=true);
           
	  //cube([front_panel_x, front_panel_y, th], center=true);
     }
}

module base()
{
     translate([0, 288/2, -9.5])
	  cube([231, 288, 1.5], center=true);
}

module base_support(dir)
{
     translate([0, 2, 55.6])
	  rotate([-4, 0, 0])
	  cube([10, 10, 65], center=true);
     
     cube([10, 10, 50], center=true);
    
     translate([dir*10, 0, -22.5])
	  cube([20, 10, 5], center=true); 

     translate([0, 10, -22.5])
	  cube([10, 20, 5], center=true); 
    
}

// 3D printed name plate. needs to be painted to match the original colour scheme.
// Embossed writing should helpo the painting.
// name plate is an engraved outline with a vinyl sticker
// stuck on top. So no separate part.

module name_plate_core()
{
if ( 0 )
{
     rotate([-4, 0, 0])
	  cube([38, 1.5, 8.5], center=true);
	  
     translate([-38/4, 0, 0])
	  rotate([90-4, 0, 0])
	  translate([0, 0, -30])
	  cylinder(d=3, h=30);
	  
     translate([+38/4, 0, 0])
	  rotate([90-4, 0, 0])
	  translate([0, 0, -30])
	  cylinder(d=3, h=30);
} 
}

module name_plate_writing()
{
      translate([-15, -0.8, -4])
      rotate([90-4, 0, 0])
	  linear_extrude(height = 0.7, center = true, convexity = 10,twist=0)
	  import("../name_plate_writing.dxf");
}

module name_plate()
{
     translate([-76.5, 108.1, 89.3])
     {
	  difference()
	  {
	       name_plate_core();
	       name_plate_writing();
	  }
     }
}

module left_support()
{
     difference()
     {   
	  base_support(1);
	  translate([0, 15, -40])
	       cylinder(d=3.5, h=40);
	  translate([15, 0, -40])
	       cylinder(d=3.5, h=40);
     }
     //translate([28, 2, 73])
	  //rotate([-4, 0, 0])
	  //cube([38+9, 5, 17], center=true); 

     if (show_lh_ruler)
       {
       translate([20, 0, 32.5])
       cube([10,10,115], center=true);
       }
}

rh_pl_x = 29;
rh_pl_z = 32;
sw_pl_hole_x = 24;
sw_pl_hole_z = 27;
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

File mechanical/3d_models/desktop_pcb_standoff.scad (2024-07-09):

// Stand offs for the desktop version of the experimental
// schools computer

$fn = 100;

module pre()
{
    cube([8, 8, 11], center=true);
}

module rem()
{
    cylinder(d=1.5, h=11+0.1, center=true);
}


module standoff()
{
difference()
    {
        pre();
        rem();
    }
}


standoff();

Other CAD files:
mechanical/esc_case.dxf
mechanical/3d_models/cased_desktop_rh_stand.stl
mechanical/front_panel_62mm_name_recess_only.dxf
mechanical/3d_models/cased_desktop_left_support.stl
mechanical/3d_models/kb_support.scad
mechanical/3d_models/cased_desktop.dxf
mechanical/3d_models/desktop_pcb_standoff.stl
mechanical/3d_models/overlay1-F_SilkS.dxf
mechanical/3d_models/overlay_and_front_panel_alignment.dxf
mechanical/3d_models/television.scad
mechanical/3d_models/television_bezel.stl
mechanical/3d_models/television_bezel_v2.stl
mechanical/3d_models/television_rear_bottom_panel_v2.stl
mechanical/3d_models/television_rear_top_panel_v2.stl
mechanical/3d_models/tv_spacer_corner.stl
mechanical/3d_models/tv_spacers.scad
mechanical/Untitled.dxf
mechanical/esc_case_backup.dxf
mechanical/esc_desktop_case_grill_cnc.dxf
mechanical/front_panel.dxf
mechanical/front_panel2.dxf
mechanical/front_panel_0mm_tool.dxf
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

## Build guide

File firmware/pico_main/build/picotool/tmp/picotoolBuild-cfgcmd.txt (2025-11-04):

cmd='/usr/bin/cmake;--no-warn-unused-cli;-DCMAKE_MAKE_PROGRAM:FILEPATH=/usr/bin/gmake;-DPICO_SDK_PATH:FILEPATH=/home/menadue/pico/pico-sdk;-DPICOTOOL_NO_LIBUSB=1;-DPICOTOOL_FLAT_INSTALL=1;-DCMAKE_INSTALL_PREFIX=/home/menadue/tree/github/experimental-computer-for-schools/firmware/pico_main/build/_deps;-DCMAKE_RULE_MESSAGES=OFF;-DCMAKE_INSTALL_MESSAGE=NEVER;-GUnix Makefiles;-S;<SOURCE_DIR><SOURCE_SUBDIR>;-B;<BINARY_DIR>'

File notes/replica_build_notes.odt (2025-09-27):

# Experimental School’s Computer Replica

# Build Notes

The replica is based on a Raspberry Pi Pico module. This has an RP2040mirocontroller on it, together with RAM and flash. The replica uses the microcontroller to emulate the processor in the school’s computer, scan the keyboard and drive a display. There is an SD card slot for storage of the state of the replica, this replaces the external tape recorder that the original used for storage.

PCB Assembly

The PCB uses surface mount components, but is hand solder-able. The SD card socket is best soldered first so there is plenty of access around the component. NOTE: Ensure the plastic pins on the underside of the SD card holder are removed as the footprint does not have holes for these and the holder will not sit flush with the PCB if they are not removed. A large tip will be needed on the soldering iron in order to heat up the mechanical tabs that attach to the ground plane.

The Pico can be soldered direct to the PCB or mounted in a pin header socket. If mounted to the PB then it should be viewed as a permanent attachment. Picos are not easy to remove once soldered down. A Pico or a Pico W can be used. A wifi hotspot is generated and access to the display and keys of the replica are possible over this if a Pico W is used. USB control is possible on the Pico and Pico W. The hardware display and keys are also available on the Pico and Pico W.

The PCB has several solder linsk that are used for configuration:

JP1:

JP2:

JP3:

JP4:

JP5: Link this to run the 3V3 from the 3V3 regulator (and the Pio from the 5V connector)

JP6: Link this to run the 3V3 from the Pico and off USB (default)

To run the PCB off a USB cable attched to the Pico, link JP6 and do not link JP5. Determine power of I2C display and link two of JP1-4.

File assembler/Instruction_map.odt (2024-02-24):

Experimental Computer for Schools Instruction Map

b | a-> | 0 | 1 | 2 | 3 | 4 | 5 | 6 | 7 | 8 | 9
0 | | (Rc)<-(Rc)+d | (Rc)<-(Rc)+(Rd) | Copy (Aa) into R0 and R1 | Copy (Aa) into R0 and R1 | Copy (Aa) into R0 and R1 | Copy (Aa) into R0 and R1 | Copy (Aa) into R0 and R1 | (Aa1)<-(Aa2)+(Aa3) | (Aa1)<-(Aa2)+(Aa3) | (Aa1)<-(Aa2)+(Aa3)
1 | | (Rc)<-(Rc)-d | (Rc)<-(Rc)-(Rd) | Store R0 and R1 in Aa in data format | Store R0 and R1 in Aa in data format | Store R0 and R1 in Aa in data format | Store R0 and R1 in Aa in data format | Store R0 and R1 in Aa in data format | (Aa1)<-(Aa2)-(Aa3) | (Aa1)<-(Aa2)-(Aa3) | (Aa1)<-(Aa2)-(Aa3)
2 | | (Rc)<-d-(Rc) | (Rc)<-(Rd)-(Rc) | Store R0 and R1 in Aa in instruction format | Store R0 and R1 in Aa in instruction format | Store R0 and R1 in Aa in instruction format | Store R0 and R1 in Aa in instruction format | Store R0 and R1 in Aa in instruction format | (Aa1)<-(Aa2)*(Aa3) | (Aa1)<-(Aa2)*(Aa3) | (Aa1)<-(Aa2)*(Aa3)
3 | | (Rc)<-d | (Rc)<-(Rd) | | | | | | (Aa1)<-(Aa2)/(Aa3) | (Aa1)<-(Aa2)/(Aa3) | (Aa1)<-(Aa2)/(Aa3)
4 | | | Copy sign and RH size digits of Rd into Rc | Unconditional branch to Aa, Store link address in Rlink | Unconditional branch to Aa, Store link address in Rlink | Unconditional branch to Aa, Store link address in Rlink | Unconditional branch to Aa, Store link address in Rlink | Unconditional branch to Aa, Store link address in Rlink | Branch to Aa1 if (Aa2) = (Aa3) | Branch to Aa1 if (Aa2) = (Aa3) | Branch to Aa1 if (Aa2) = (Aa3)
5 | | Test (Rc) | | Branch to Aa if CL=1 Store links address in Rlink | Branch to Aa if CL=1 Store links address in Rlink | Branch to Aa if CL=1 Store links address in Rlink | Branch to Aa if CL=1 Store links address in Rlink | Branch to Aa if CL=1 Store links address in Rlink | Branch to Aa1 if (Aa2) > (Aa3) | Branch to Aa1 if (Aa2) > (Aa3) | Branch to Aa1 if (Aa2) > (Aa3)
6 | | Left Shift (Rc) by d places | Left Shift (Rc) by (Rd) places | Branch to Aa if CL=0 Store links address in Rlink | Branch to Aa if CL=0 Store links address in Rlink | Branch to Aa if CL=0 Store links address in Rlink | Branch to Aa if CL=0 Store links address in Rlink | Branch to Aa if CL=0 Store links address in Rlink | Branch to Aa1 if |(Aa2)| > |(Aa3)| | Branch to Aa1 if |(Aa2)| > |(Aa3)| | Branch to Aa1 if |(Aa2)| > |(Aa3)
7 | | Right Shift (Rc) by d places | Right Shift (Rc) by (Rd) places | Store Rlink in Aa | Store Rlink in Aa | Store Rlink in Aa | Store Rlink in Aa | Store Rlink in Aa | If (Aa1) <> 0 branch to (Aa2) and store Rlink in (Aa3) | If (Aa1) <> 0 branch to (Aa2) and store Rlink in (Aa3) | If (Aa1) <> 0 branch to (Aa2) and store Rlink in (Aa3)
8 | | | | Input Aa | Input Aa | Input Aa | Input Aa | Input Aa | Input (Aa1) and display (Aa1),(Aa2),(Aa3) | Input (Aa1) and display (Aa1),(Aa2),(Aa3) | Input (Aa1) and display (Aa1),(Aa2),(Aa3)
9 | | | Stop and display Rc and Rd | Display Aa | Display Aa | Display Aa | Display Aa | Display Aa | Stop and display (Aa1), (Aa2), (Aa3) | Stop and display (Aa1), (Aa2), (Aa3) | Stop and display (Aa1), (Aa2), (Aa3)

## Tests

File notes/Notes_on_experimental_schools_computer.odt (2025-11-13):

# Notes on Experimental Schools Computer

## Words

The documents refer to words as storing decimal digits. There is mention of a decimal digit being 4 bits. This is useful as it implies that the sign is stored as 4 bits, but presumably one of the codes that don’t represent a decimal digit: A-F in hexadecimal. The actual code used for positive and negative don’t seem to be mentioned. A decimal digit can’t be used as even though the sign digit is in a position that is never a digit for a floating point word, the sign is used to detect an instruction when an instruction is loaded from store. Instructions use all of the decimal digits. On a real machine a floating point word could be loaded in to a register and examined to determine the sign codes.

## Instructions

Basic instructions are stored two to a word in the store. There's not a lot of information about how these two words are executed. The simulator assumes one is executed and then the next. The instruction at digits 1-4 is executed first and then the 5-8 digits.

How this is done when the A,B and C keys are pressed is unknown as there isn’t any information at this detail yet. For now, just running the top basic instruction is enough to get the simulator running, then the lower instruction execution can be added.

From the instruction card:

This shows how two instructions in a single word are executed after entering them from the keyboard using the KI RESET key. It implies that the sequence of keys to execute it is A, B, C, A, B, C. The simulator works on this sequential execution of two instructions in one word.

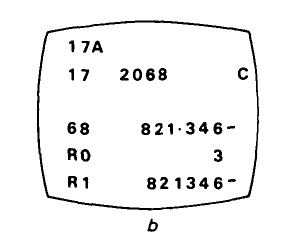
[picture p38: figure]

The examples of display sometimes show an interesting extra character. Display ‘b’ here, shows a 17A in the IAR position and below it the auxiliary IAR of 17. This implies that the 2068 four digit instruction is at the first four digits of a word and the second four digit instruction is at what it calls the ‘A’ position, 17A in this case. Stage C displays the next instruction address in the IAR and the currently processed instruction in the auxiliary IAR.

Similarly, display ‘d’ shows the completion of an instruction at address 18A and the IAR is showing the address of the next instruction at address 19. This confirms the ordering of the nn and nnA addressing.

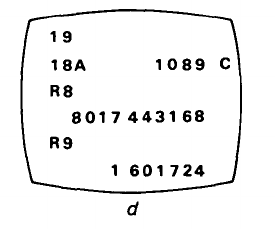
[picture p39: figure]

These screens imply an extra bit or flag associated with the IAR that is used to execute the pairs of 4 digit instructions.

## Instruction Stages

The simulator tries to give a display of the stages and use the stages as the original computer did, but there aren’t many examples of the stages and their display.

## Stage A Display

There is an example of the stage A display in the IET paper. Displays for other instructions aren’t available.

This stage A display is a

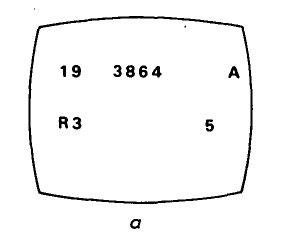
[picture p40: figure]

## Stage B Displays

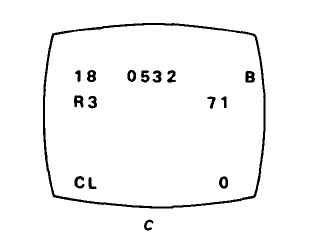
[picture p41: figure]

A stage B display is shown here. From the description given in the IET document this should be a stage C display as the instruction (a compare of R3 with 2) has been executed and the control latch value is shown. This implies that the stages aren’t fixed in terms of function, but are rather three processing stages that can be used for whatever is required. The values used are displayed, using some system of determining what should be displayed, maybe a table for each instruction.

## Keyboard Register

Looking at the data flow diagrams it appears that the keyboard register cannot be used to input data directly to the registers. It can therefore be a single word register as it does not have to be able to write to R8 and R9.

The internal workings of number and instruction entry isn’t clear from the documents. When entering an instruction, the digits entered become the instruction code directly, with leading zeros not shown. Instructions are 4 or 8 digits, but must be entered as 8 digits when writing to the store. 4 digit instructions must be entered in pairs. The question of number entry is more interesting as if the digits ‘12’ are entered, if it is intended that this is a number then a sign digit must be placed in digit ‘a’, otherwise it will be interpreted as a n instruction. For negative numbers the trailing ‘-’ keypress will load a -ve sign into digit ‘a’, but for positive numbers there is no corresponding ‘+’ key. It appears that numbers have to have a decimal point when entering them, and that is the keypress that puts a +ve sign digit in digit ‘a’.

## Number format in registers

Figure 11 of the IEE document shows R8 and R9 with (double length) integers that have been added together. Registers always hold integers, floating point instructions always work with store addresses, and the extracode instructions that perform the floating point operations operate on the numbers as integers using the special instructions that load numbers into registers in parts.

The double length registers seem to have been added to allow floating point multiplication and division to be added as extracode instructions. Multiplying two 6 digit numbers requires a 12 bit result which can easily be truncated back to 6 digits. Obviously overflow occurs if the discarded digits are not in the fractional part of the number.

## Loading different size registers

There is an instruction that loads a register with the contents of another register. This instruction can load single word register with double length registers and vice versa. The behaviour of these transfers isn’t in the documentation. As the single and double size registers hold 6 and 12 digits respectively, there is room for a sign. So, when moving a single word register to a double, the 6 digits appear in the lower 6 digits of the double word register and the sign is also transferred.

When transferring a double word register to a single word register the sign is transferred and the lower 6 digits of the double word register are transferred to the lower 6 digits of the double word register. When performing arithmetic and transferring, the same rules are used.

# Core Store

The core has 222 words (32 bit) of memory.

00-99 Program space

100-199 Extracode space

200-207 R0 to R7

208,218 R8

209,218 R9

## Questions

Was it possible to enter the ‘A’ flag of the IAR from the keyboard?

There is an ‘A’ key on the keyboard but there’s no record of it being used to enter an address. If this flag wasn’t entered then the only way to run an instruction in the second 4 digits of a word is to run the first instruction followed by the second.

Addressing in extracode instructions

When single address instructions indirectly address a location in store, the address used is formed from the ‘cd’ part of the instruction, the hundreds digit comes from the hundreds digit of the IAR.

The hundreds digit of the IAR is only used when building an address using cd. When using addresses in store, the value in store is used. This is important when extracode instructions are executed e.g.:

70203040

the addresses of the operands are in store addresses 000..099, whereas the store location holding the address is in locations 100..102 (TAR1..TAR3). When an extracode indirectly addresses Z, for instance, it uses an instruction of the form:

6002

The address in store that holds the address of Z is 102 (1 from the IAR and 02 from the instruction). When 102 is read to get the address of the data, whatever is in 102 is used. That will be 40 in the example above. So, the instruction 6002 accesses a store location in 100..199 and then a location in 000..099.

https://www.cs.ox.ac.uk/research/publications/

https://www.cs.ox.ac.uk/teaching/handbooks.html

https://www.cs.ox.ac.uk/files/13731/CS%20Handbook%20final.pdf

https://maps.ox.ac.uk/bd821e30-d8ba-11eb-a363-059e537832a1

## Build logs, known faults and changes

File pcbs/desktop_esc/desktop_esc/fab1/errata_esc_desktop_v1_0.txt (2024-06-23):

ESC Desktop V1.0 Errata

0. CS_N should be CS_N_3V3   DONE
1. AO signal goes to ADC ref, which isn't a GPIO.   DONE GPIO11
2. Add 150pF caps to wr,rd,cs,cd Not needed when PCB mounted on back of LCD, added anyway.

3. Rotate the display connector by 180 degrees so it can be mounte don th ebak of the display. Reduces corruption.

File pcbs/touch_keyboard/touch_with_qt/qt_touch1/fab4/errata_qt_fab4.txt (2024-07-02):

Errata for V2.0 QT Touch Keyboard
=================================

1. GND is not good, re-instate GND plane but only along bottom of PB to supply decent GND to circuitry.
2. Minus key should not be X7 to X2 but X7 to Y2
3. Y0-Y3 are reversed, to Y3-Y0. This can be handled in code.

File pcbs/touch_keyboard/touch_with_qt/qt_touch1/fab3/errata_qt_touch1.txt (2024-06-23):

QT Touch keyboard Errata
========================

2. TX and RX are swapped on the jumpers. Not a problem.
3. CS_N and CS_N_3V3 are different signals
4. SS on QT IC is not connected, so internal pull-up is used.
5. TP8 X is not connected.
6. A and RUN have the same X and Y onnections
7. 0, 9
8. 1, 2
9. 4,5
10. 7,8
11. LOAD IAR, LOAD ADDR
12. DECR ADDR, INC ADDR
13. CLEAR, MINUS
14. C16 footprint too small for 100uF

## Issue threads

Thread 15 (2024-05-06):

Add touch keyboard scanningcode

blackjetrock, 2024-05-06:
A touch keyboard PCB has been designed and if it works will require scanning code. That will probably be going in the second core as that is unused at the moment.

blackjetrock, 2024-08-30:
UART connected touch keyboard now working. This keyboard will not be used.

Closed 2024-08-30.

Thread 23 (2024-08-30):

Desktop ESC code doesn't built with wifi

blackjetrock, 2024-08-30:
Wifi should be a valid build for the desktop ESC build.

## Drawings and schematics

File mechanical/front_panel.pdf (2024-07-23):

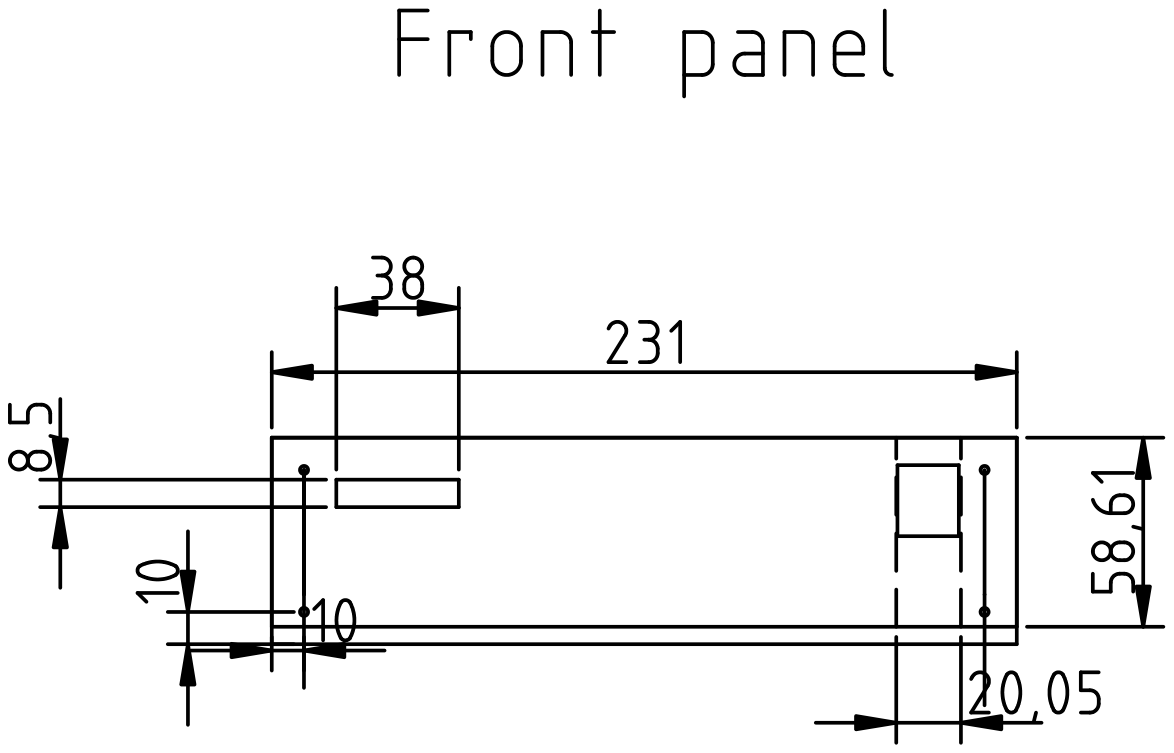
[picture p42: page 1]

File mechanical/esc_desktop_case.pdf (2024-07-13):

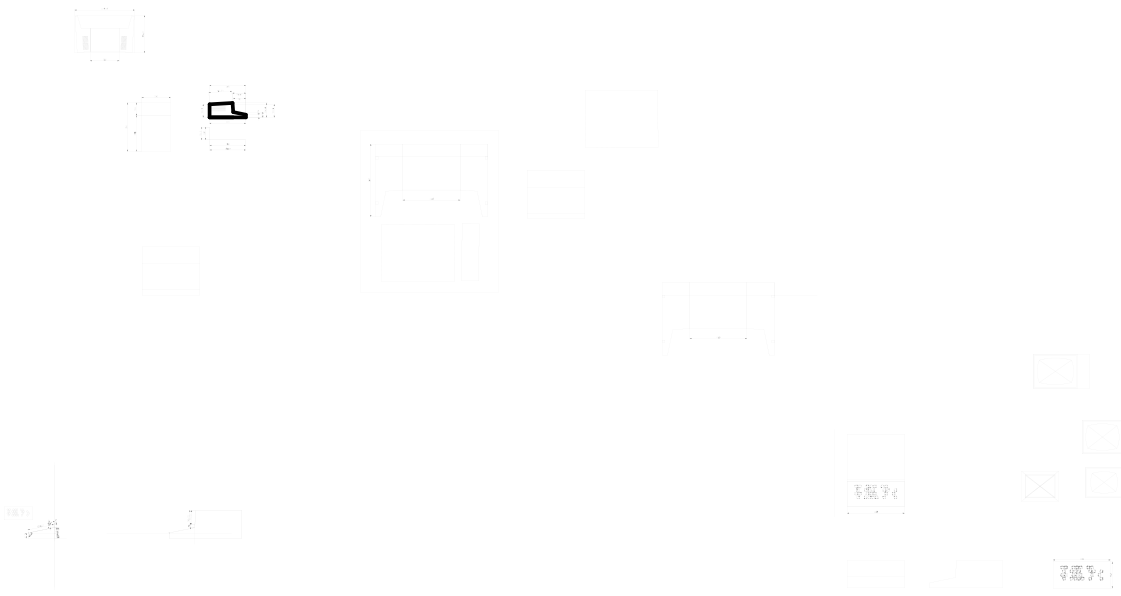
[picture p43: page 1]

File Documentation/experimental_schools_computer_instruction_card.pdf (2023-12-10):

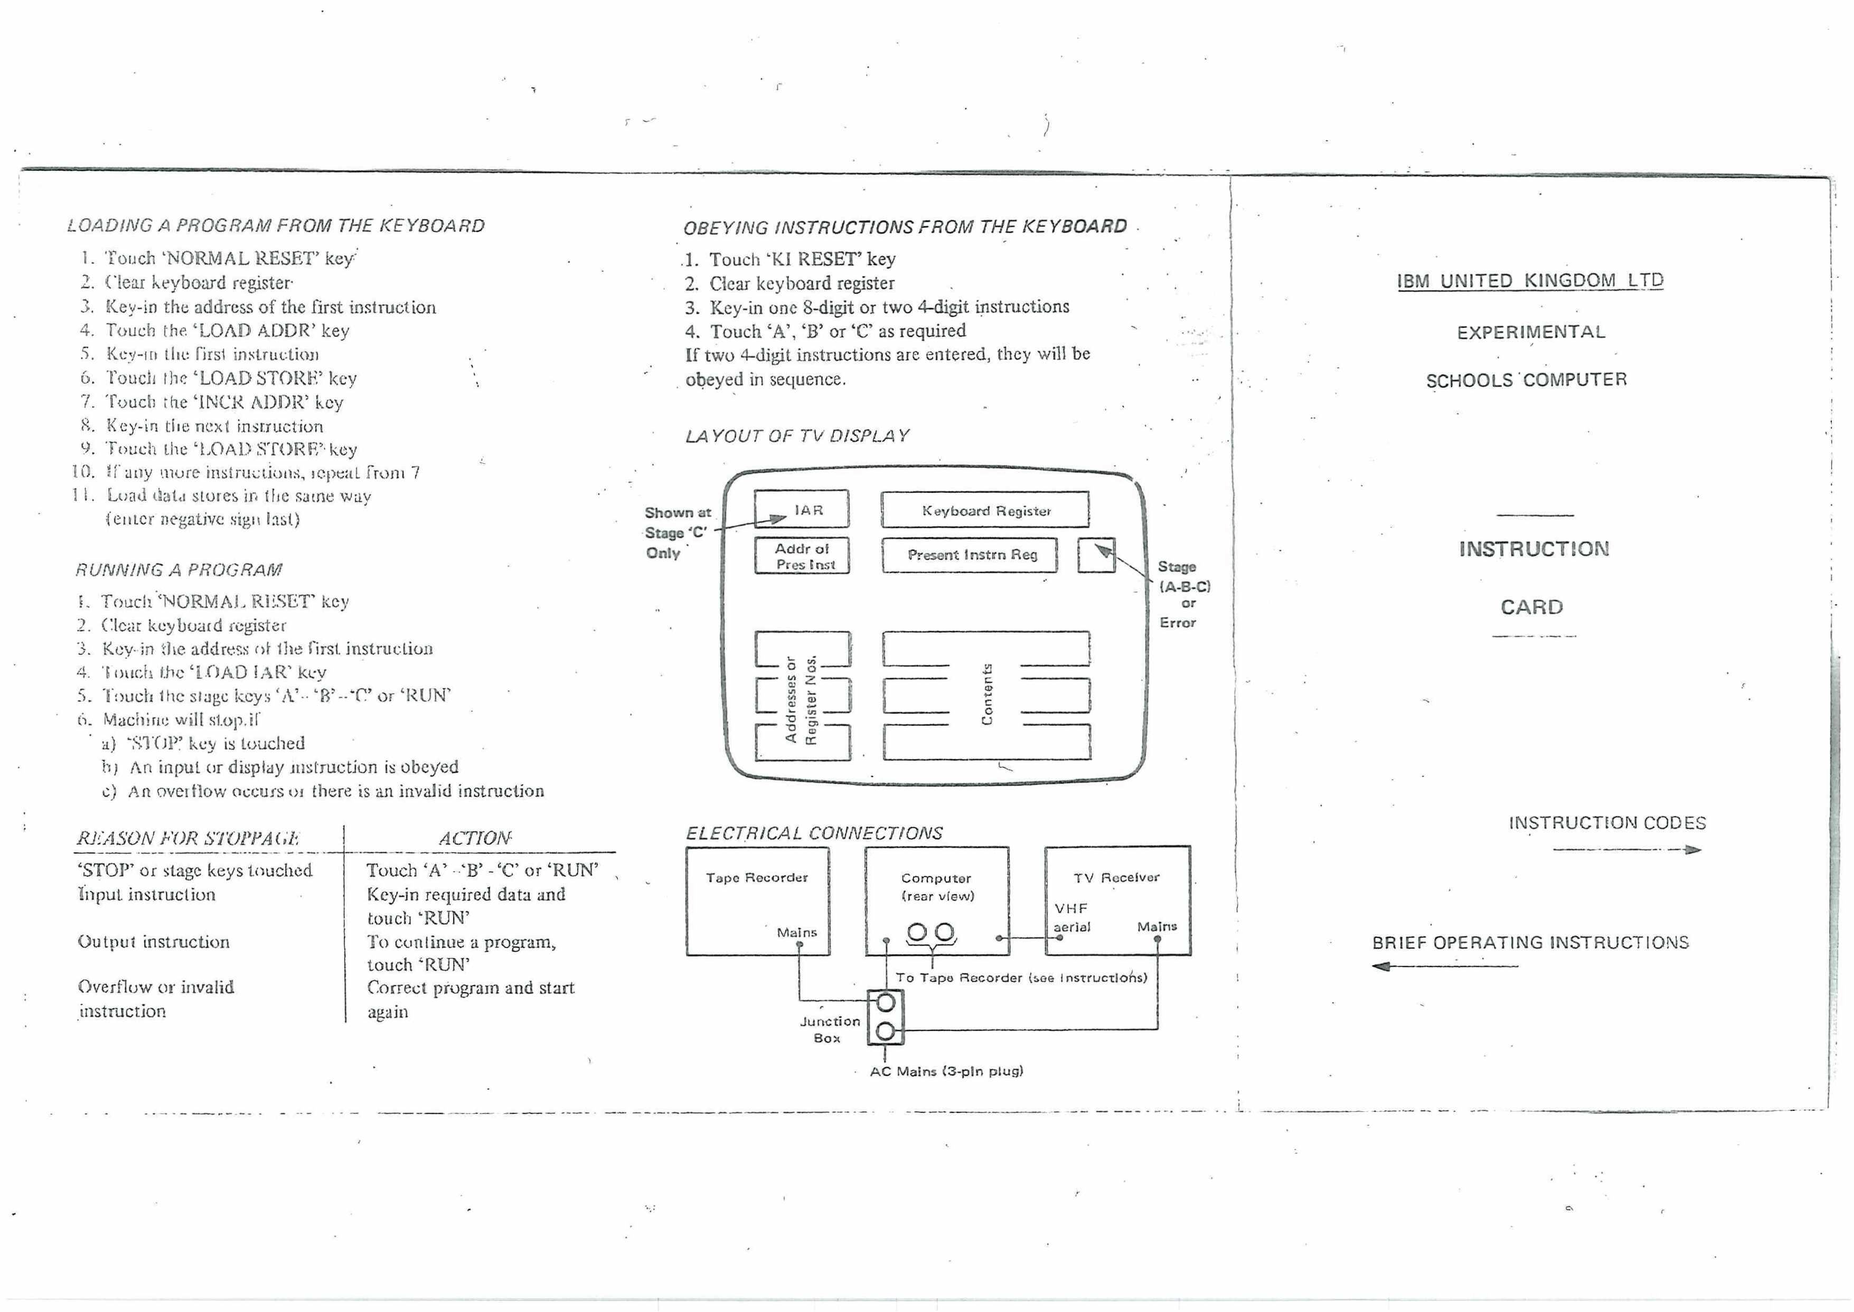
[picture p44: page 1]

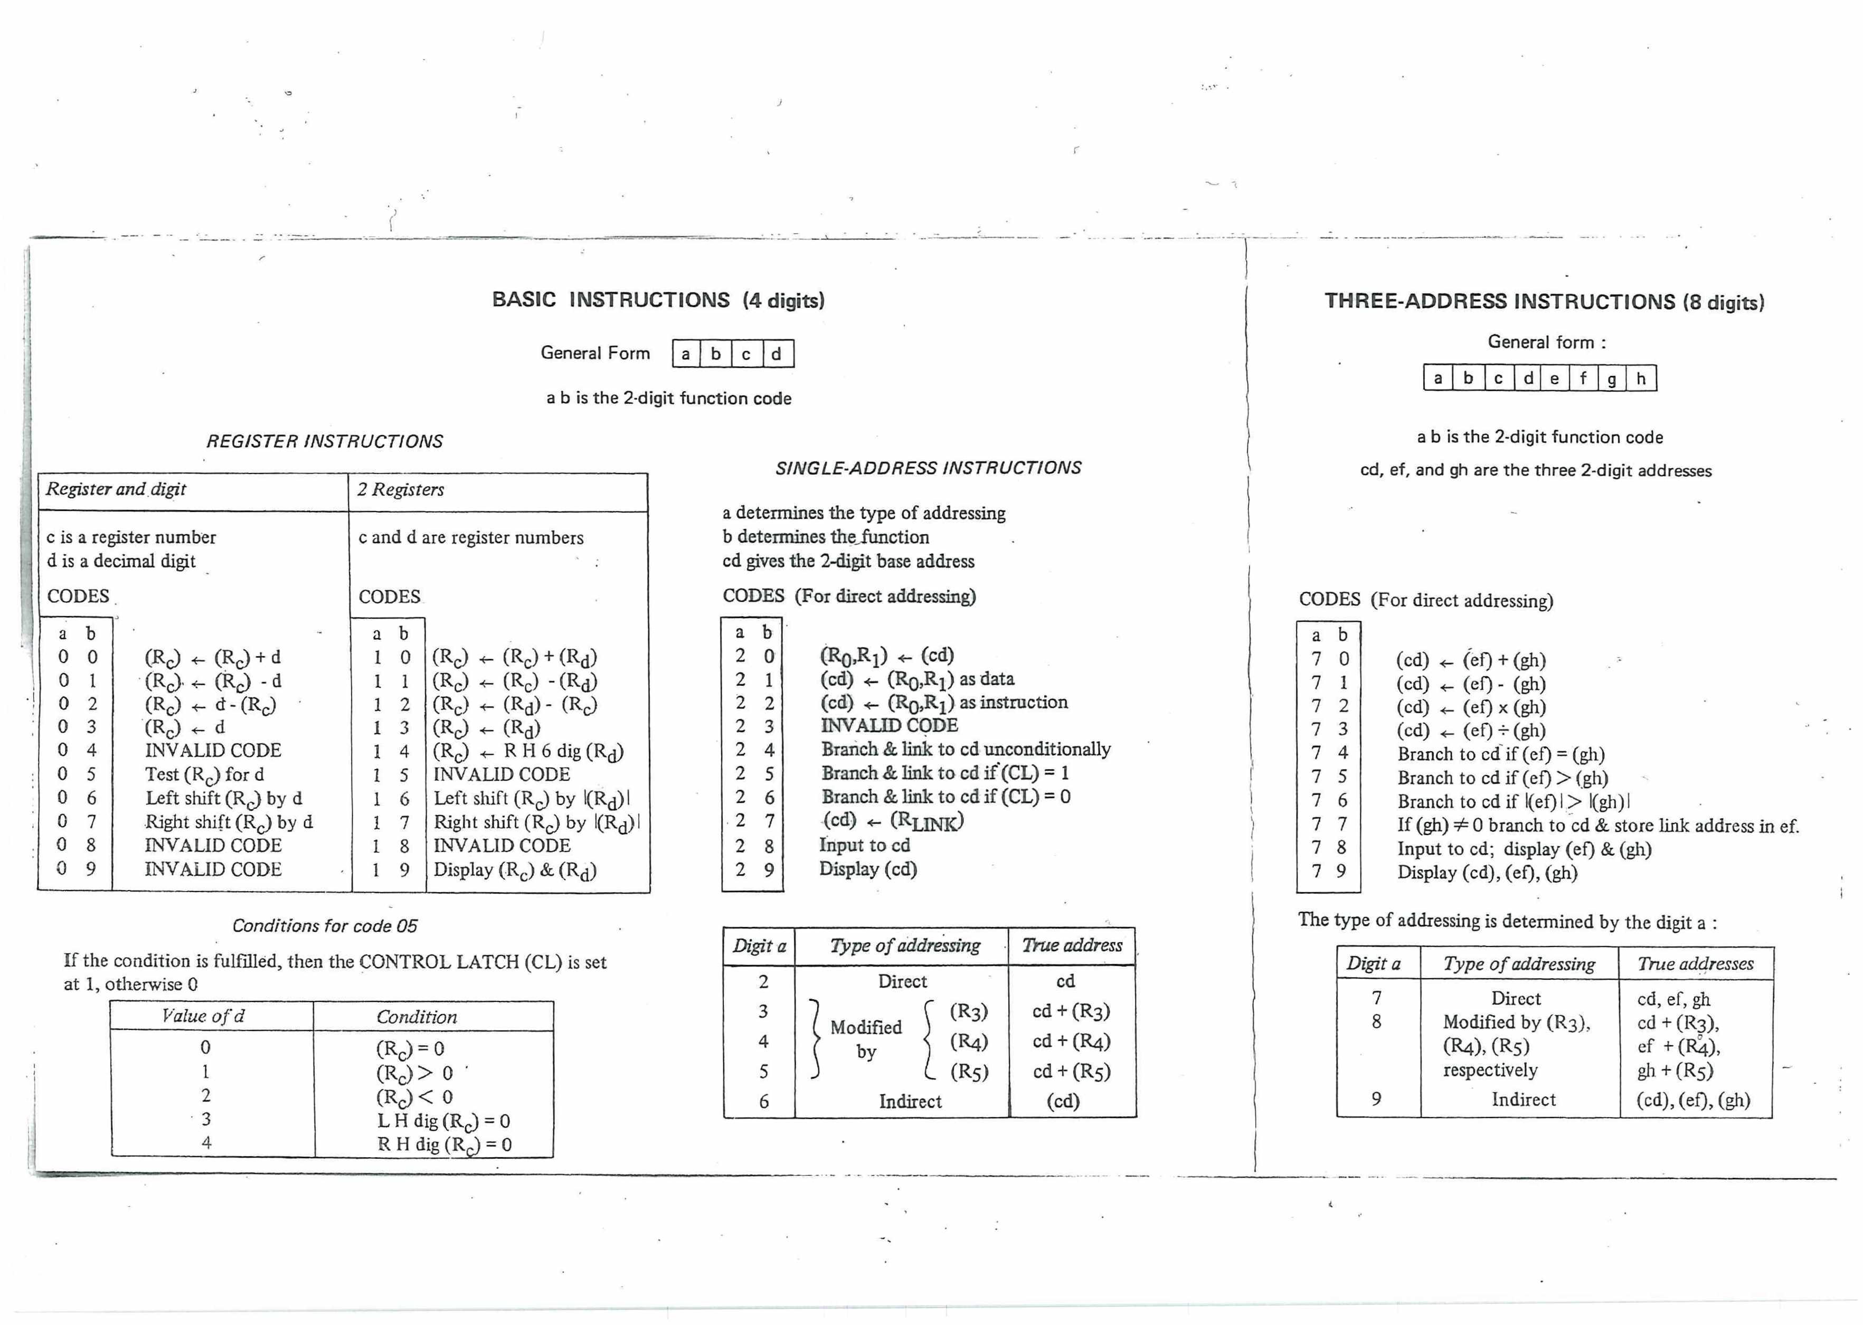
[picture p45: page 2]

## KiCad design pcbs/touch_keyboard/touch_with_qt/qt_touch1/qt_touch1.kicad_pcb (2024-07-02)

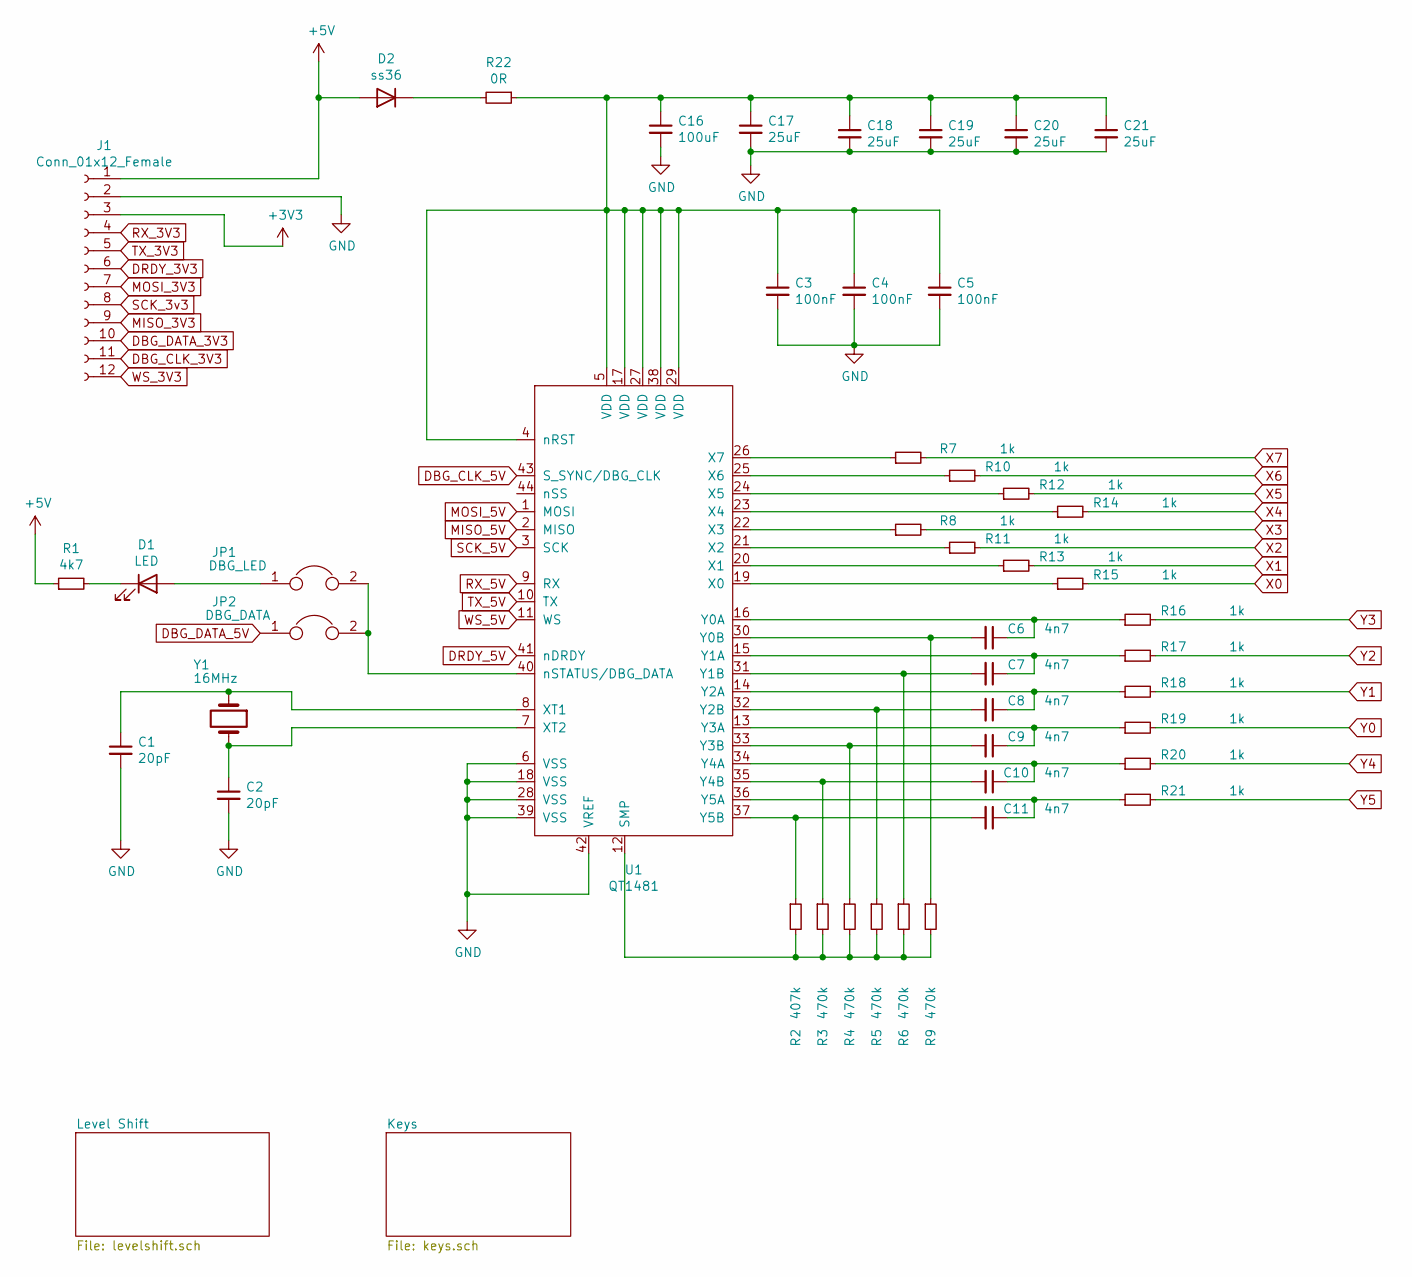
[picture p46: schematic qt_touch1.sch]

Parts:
C1, C2: 20pF; C_0805_2012Metric_Pad1.18x1.45mm_HandSolder
C3, C4, C5: 100nF; C_0805_2012Metric_Pad1.18x1.45mm_HandSolder
C6, C7, C8, C9, C10, C11: 4n7; C_0805_2012Metric_Pad1.18x1.45mm_HandSolder
C16: 100uF; C_1206_3216Metric_Pad1.33x1.80mm_HandSolder
C17, C18, C19, C20, C21: 25uF; C_1206_3216Metric_Pad1.33x1.80mm_HandSolder
D1: LED; LED_0805_2012Metric_Pad1.15x1.40mm_HandSolder
D2: ss36; LED_0805_2012Metric_Pad1.15x1.40mm_HandSolder
J1: Conn_01x12_Female; PinSocket_1x12_P2.54mm_Vertical_SMD_Pin1Left
JP1: DBG_LED; SolderJumper-2_P1.3mm_Open_TrianglePad1.0x1.5mm
JP2: DBG_DATA; SolderJumper-2_P1.3mm_Open_TrianglePad1.0x1.5mm
R1: 4k7; R_0805_2012Metric_Pad1.20x1.40mm_HandSolder
R2: 407k; R_0805_2012Metric_Pad1.20x1.40mm_HandSolder
R3, R4, R5, R6, R9: 470k; R_0805_2012Metric_Pad1.20x1.40mm_HandSolder
R7, R8, R10, R11, R12, R13, R14, R15, R16, R17, R18, R19, R20, R21: 1k; R_0805_2012Metric_Pad1.20x1.40mm_HandSolder
R22: 0R; R_0805_2012Metric_Pad1.20x1.40mm_HandSolder
U1: QT1481; LQFP-44_10x10mm_P0.8mm
Y1: 16MHz; Crystal_SMD_HC49-SD_HandSoldering

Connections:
+3V3: J1.3; also elsewhere on the board
+5V: D2.2 (A), J1.1, R1.1; also elsewhere on the board
DBG_CLK_5V: U1.43 (S_SYNC/DBG_CLK); also elsewhere on the board
DBG_DATA_3V3: J1.10; also elsewhere on the board
DBG_DATA_5V: JP2.1; also elsewhere on the board
DRDY_3V3: J1.6; also elsewhere on the board
DRDY_5V: U1.41 (nDRDY); also elsewhere on the board
GND: C1.2, C2.2, C3.2, C4.2, C5.2, C16.2, C17.2, C18.2, C19.2, C20.2, C21.2, J1.2, U1.6 (VSS), U1.18 (VSS), U1.28 (VSS), U1.39 (VSS), U1.42 (VREF); also elsewhere on the board
MISO_3V3: J1.9; also elsewhere on the board
MISO_5V: U1.2 (MISO); also elsewhere on the board
MOSI_3V3: J1.7; also elsewhere on the board
MOSI_5V: U1.1 (MOSI); also elsewhere on the board
unnamed: C1.1, U1.8 (XT1), Y1.1
unnamed: C2.1, U1.7 (XT2), Y1.2
unnamed: C6.1, R16.1, U1.16 (Y0A)
unnamed: C6.2, R9.1, U1.30 (Y0B)
unnamed: C7.1, R17.1, U1.15 (Y1A)
unnamed: C7.2, R6.1, U1.31 (Y1B)
unnamed: C8.1, R18.1, U1.14 (Y2A)
unnamed: C8.2, R5.1, U1.32 (Y2B)
unnamed: C9.1, R19.1, U1.13 (Y3A)
unnamed: C9.2, R4.1, U1.33 (Y3B)
unnamed: C10.1, R20.1, U1.34 (Y4A)
unnamed: C10.2, R3.1, U1.35 (Y4B)
unnamed: C11.1, R21.1, U1.36 (Y5A)
unnamed: C11.2, R2.1, U1.37 (Y5B)
unnamed: C3.1, C4.1, C5.1, C16.1, C17.1, C18.1, C19.1, C20.1, C21.1, R22.1, U1.4 (nRST), U1.5 (VDD), U1.17 (VDD), U1.27 (VDD), U1.29 (VDD), U1.38 (VDD)
unnamed: D1.1 (K), R1.2
unnamed: D1.2 (A), JP1.1
unnamed: D2.1 (K), R22.2
unnamed: JP1.2, JP2.2, U1.40 (nSTATUS/DBG_DATA)
unnamed: R2.2, R3.2, R4.2, R5.2, R6.2, R9.2, U1.12 (SMP)
unnamed: R7.1, U1.26 (X7)
unnamed: R8.1, U1.22 (X3)
unnamed: R10.1, U1.25 (X6)
unnamed: R11.1, U1.21 (X2)
unnamed: R12.1, U1.24 (X5)
unnamed: R13.1, U1.20 (X1)
unnamed: R14.1, U1.23 (X4)
unnamed: R15.1, U1.19 (X0)
RX_3V3: J1.4; also elsewhere on the board
RX_5V: U1.9 (RX); also elsewhere on the board
SCK_5V: U1.3 (SCK); also elsewhere on the board
TX_3V3: J1.5; also elsewhere on the board
TX_5V: U1.10 (TX); also elsewhere on the board
WS_3V3: J1.12; also elsewhere on the board
WS_5V: U1.11 (WS); also elsewhere on the board
X0: R15.2; also elsewhere on the board
X1: R13.2; also elsewhere on the board
X2: R11.2; also elsewhere on the board
X3: R8.2; also elsewhere on the board
X4: R14.2; also elsewhere on the board
X5: R12.2; also elsewhere on the board
X6: R10.2; also elsewhere on the board
X7: R7.2; also elsewhere on the board
Y0: R19.2; also elsewhere on the board
Y1: R18.2; also elsewhere on the board
Y2: R17.2; also elsewhere on the board
Y3: R16.2; also elsewhere on the board
Y4: R20.2; also elsewhere on the board
Y5: R21.2; also elsewhere on the board

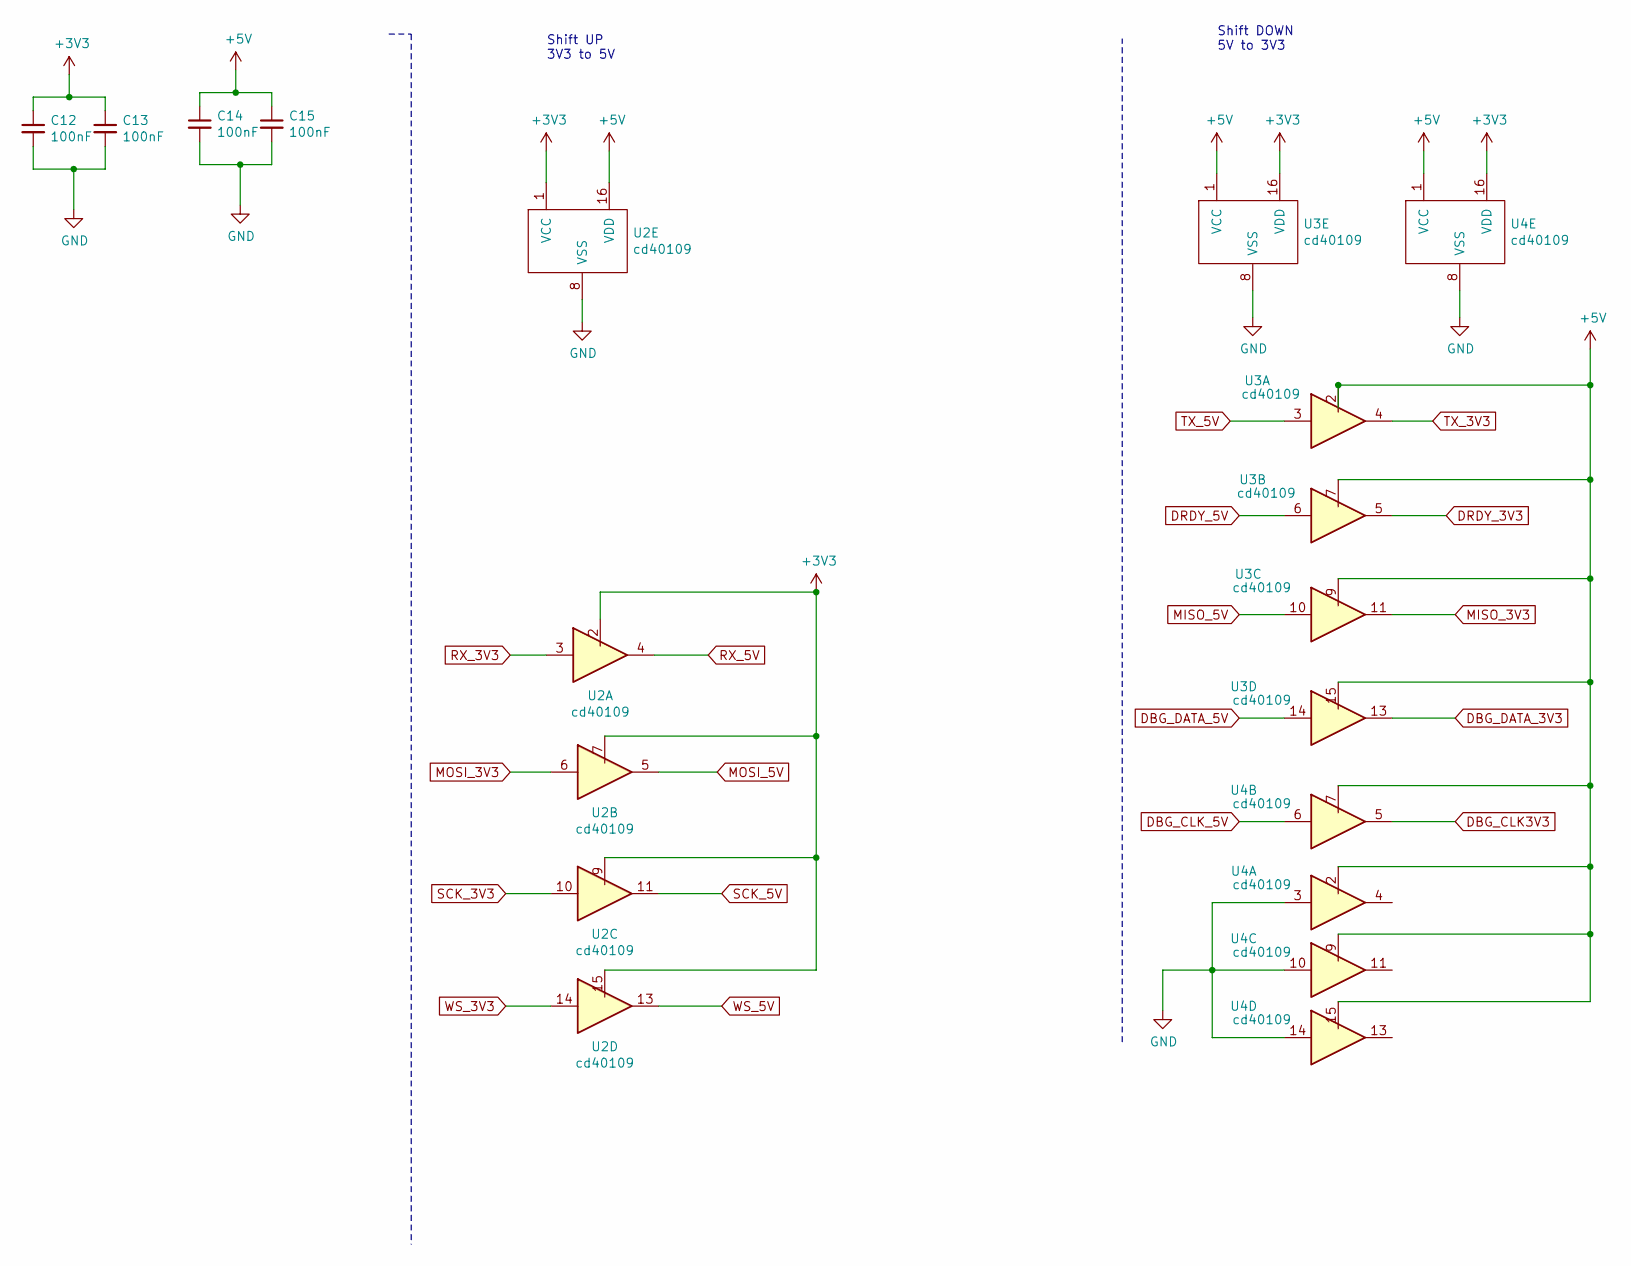
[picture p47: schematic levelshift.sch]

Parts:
C12, C13, C14, C15: 100nF; C_0805_2012Metric_Pad1.18x1.45mm_HandSolder
U2, U3, U4: cd40109; SOIC-16W_7.5x10.3mm_P1.27mm

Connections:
+3V3: C12.1, C13.1, U2.1 (VCC), U2.2, U2.7, U2.9, U2.15, U3.16 (VDD), U4.16 (VDD); also elsewhere on the board
+5V: C14.1, C15.1, U2.16 (VDD), U3.1 (VCC), U3.2, U3.7, U3.9, U3.15, U4.1 (VCC), U4.2, U4.7, U4.9, U4.15; also elsewhere on the board
DBG_CLK_5V: U4.6; also elsewhere on the board
DBG_DATA_3V3: U3.13; also elsewhere on the board
DBG_DATA_5V: U3.14; also elsewhere on the board
DRDY_3V3: U3.5; also elsewhere on the board
DRDY_5V: U3.6; also elsewhere on the board
GND: C12.2, C13.2, C14.2, C15.2, U2.8 (VSS), U3.8 (VSS), U4.3, U4.8 (VSS), U4.10, U4.14; also elsewhere on the board
MISO_3V3: U3.11; also elsewhere on the board
MISO_5V: U3.10; also elsewhere on the board
MOSI_3V3: U2.6; also elsewhere on the board
MOSI_5V: U2.5; also elsewhere on the board
RX_3V3: U2.3; also elsewhere on the board
RX_5V: U2.4; also elsewhere on the board
SCK_5V: U2.11; also elsewhere on the board
TX_3V3: U3.4; also elsewhere on the board
TX_5V: U3.3; also elsewhere on the board
WS_3V3: U2.14; also elsewhere on the board
WS_5V: U2.13; also elsewhere on the board

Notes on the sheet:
Shift UP 3V3 to 5V
Shift DOWN 5V to 3V3

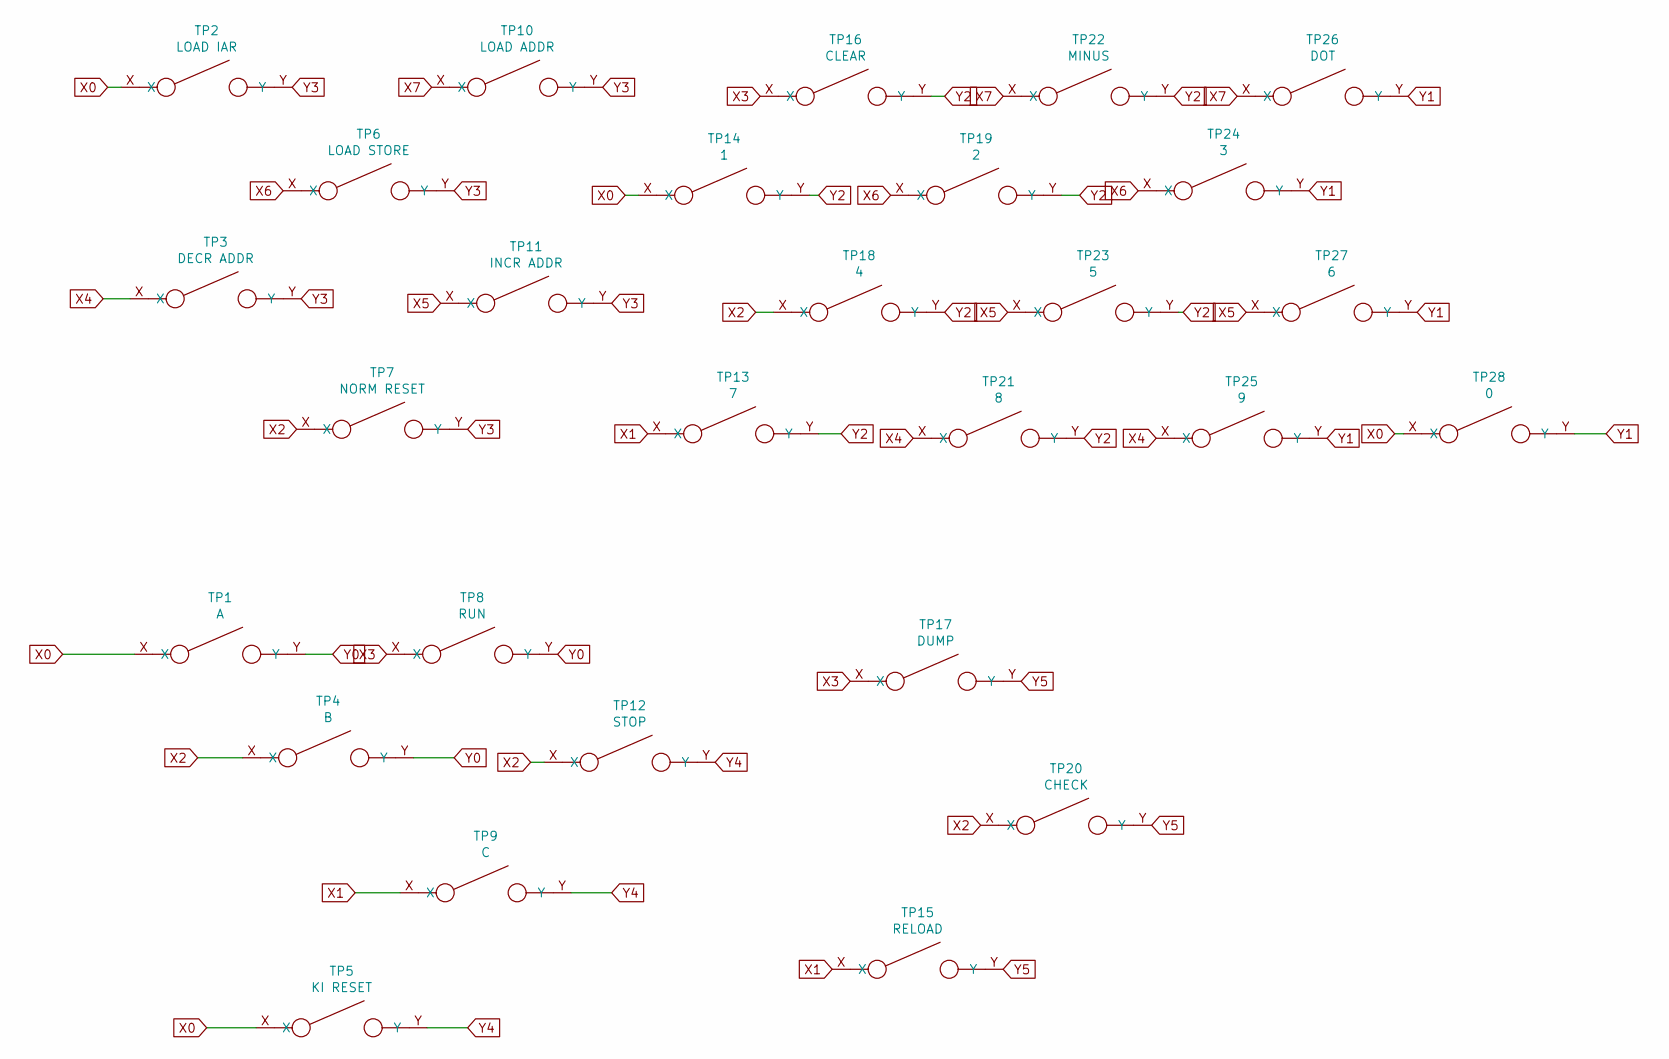
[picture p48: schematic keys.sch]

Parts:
TP1: A; qt_touch_12_x_12
TP2: LOAD IAR; qt_touch_12_x_12
TP3: DECR ADDR; qt_touch_12_x_12
TP4: B; qt_touch_12_x_12
TP5: KI RESET; qt_touch_12_x_12
TP6: LOAD STORE; qt_touch_12_x_12
TP7: NORM RESET; qt_touch_12_x_12
TP8: RUN; qt_touch_12_x_12
TP9: C; qt_touch_12_x_12
TP10: LOAD ADDR; qt_touch_12_x_12
TP11: INCR ADDR; qt_touch_12_x_12
TP12: STOP; qt_touch_12_x_12
TP13: 7; qt_touch_12_x_12
TP14: 1; qt_touch_12_x_12
TP15: RELOAD; qt_touch_12_x_12
TP16: CLEAR; qt_touch_12_x_12
TP17: DUMP; qt_touch_12_x_12
TP18: 4; qt_touch_12_x_12
TP19: 2; qt_touch_12_x_12
TP20: CHECK; qt_touch_12_x_12
TP21: 8; qt_touch_12_x_12
TP22: MINUS; qt_touch_12_x_12
TP23: 5; qt_touch_12_x_12
TP24: 3; qt_touch_12_x_12
TP25: 9; qt_touch_12_x_12
TP26: DOT; qt_touch_12_x_12
TP27: 6; qt_touch_12_x_12
TP28: 0; qt_touch_12_x_12

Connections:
X0: TP1.X, TP2.X, TP5.X, TP14.X, TP28.X; also elsewhere on the board
X1: TP9.X, TP13.X, TP15.X; also elsewhere on the board
X2: TP4.X, TP7.X, TP12.X, TP18.X, TP20.X; also elsewhere on the board
X3: TP8.X, TP16.X, TP17.X; also elsewhere on the board
X4: TP3.X, TP21.X, TP25.X; also elsewhere on the board
X5: TP11.X, TP23.X, TP27.X; also elsewhere on the board
X6: TP6.X, TP19.X, TP24.X; also elsewhere on the board
X7: TP10.X, TP22.X, TP26.X; also elsewhere on the board
Y0: TP1.Y, TP4.Y, TP8.Y; also elsewhere on the board
Y1: TP24.Y, TP25.Y, TP26.Y, TP27.Y, TP28.Y; also elsewhere on the board
Y2: TP13.Y, TP14.Y, TP16.Y, TP18.Y, TP19.Y, TP21.Y, TP22.Y, TP23.Y; also elsewhere on the board
Y3: TP2.Y, TP3.Y, TP6.Y, TP7.Y, TP10.Y, TP11.Y; also elsewhere on the board
Y4: TP5.Y, TP9.Y, TP12.Y; also elsewhere on the board
Y5: TP15.Y, TP17.Y, TP20.Y; also elsewhere on the board

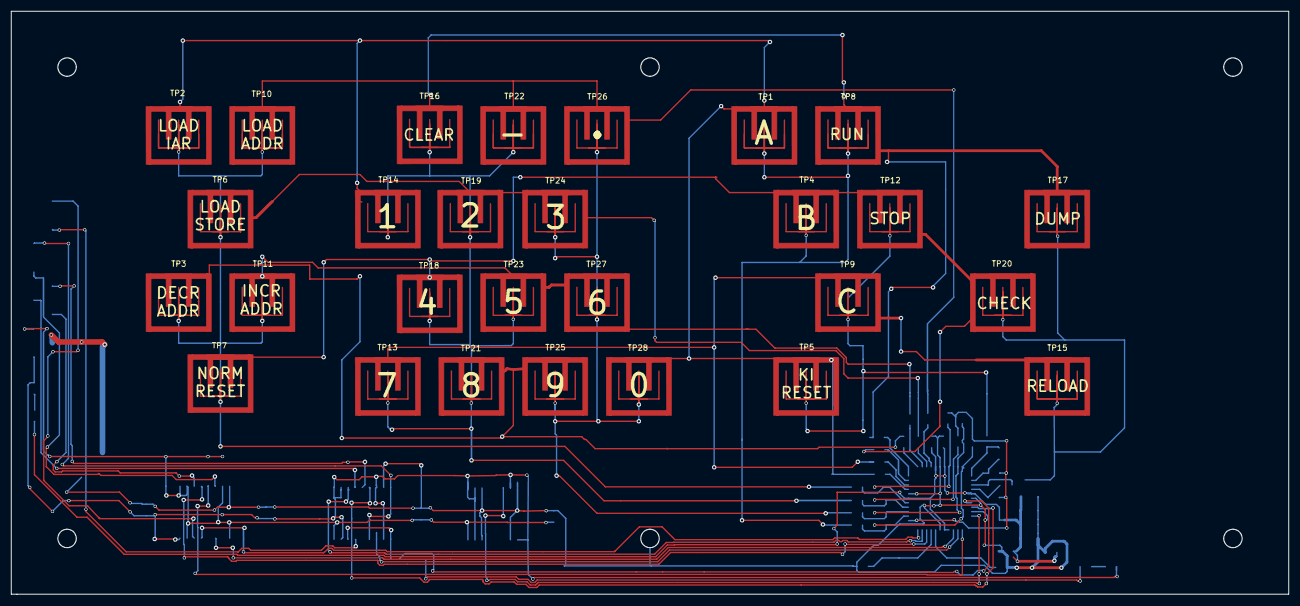
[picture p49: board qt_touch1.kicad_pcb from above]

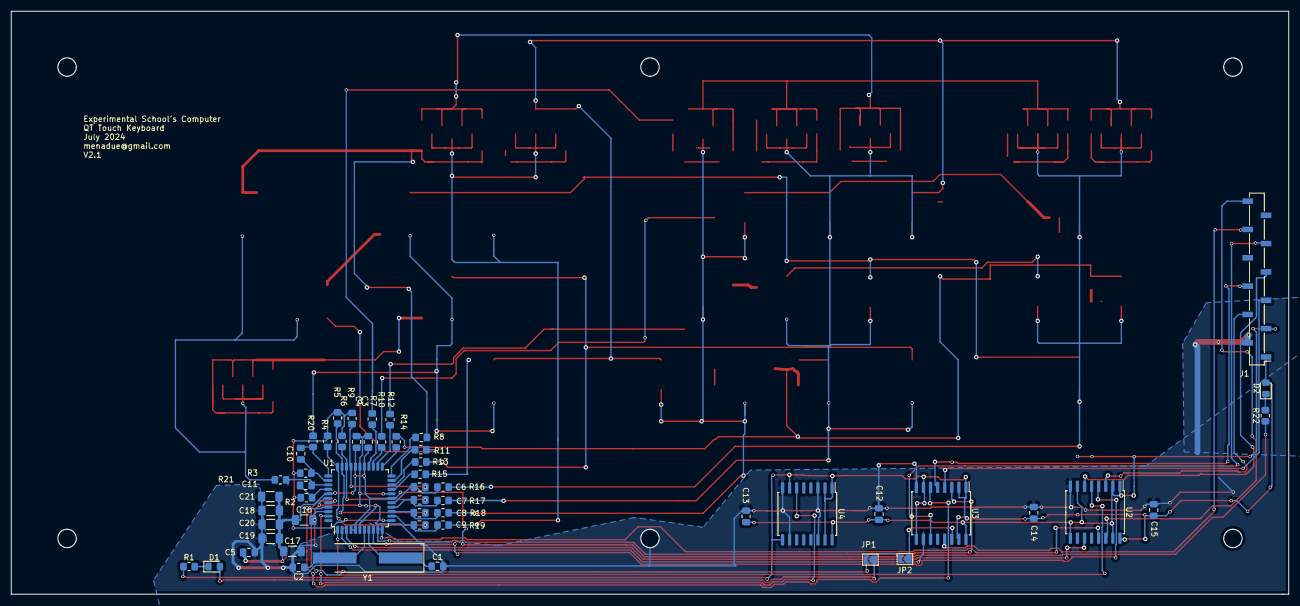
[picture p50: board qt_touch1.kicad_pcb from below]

Board: 2 copper layers, 229.0 x 104.5 mm, 81 parts (53 on the bottom side), 61 nets.

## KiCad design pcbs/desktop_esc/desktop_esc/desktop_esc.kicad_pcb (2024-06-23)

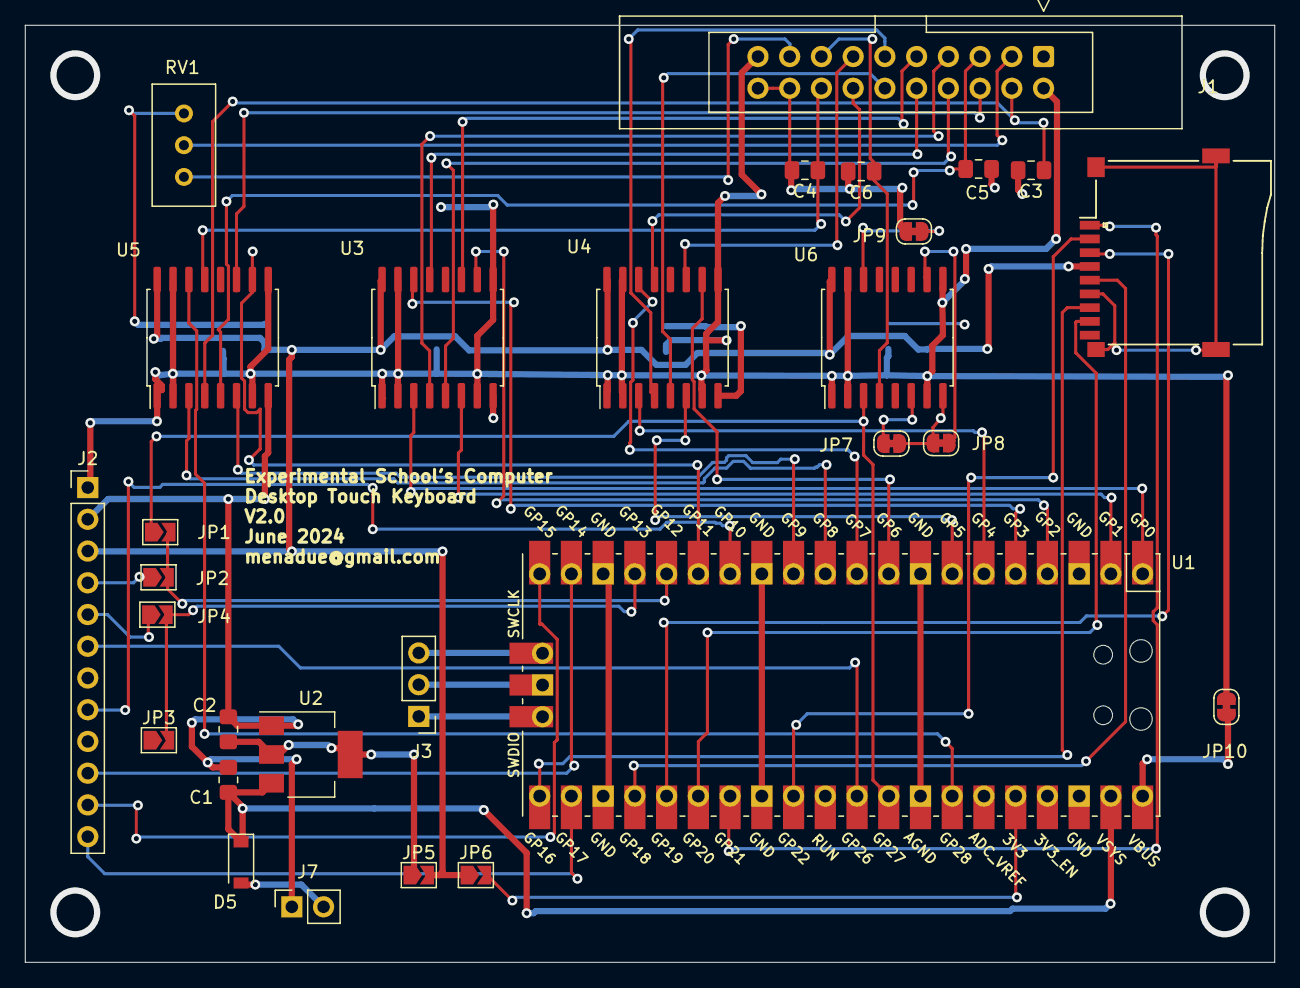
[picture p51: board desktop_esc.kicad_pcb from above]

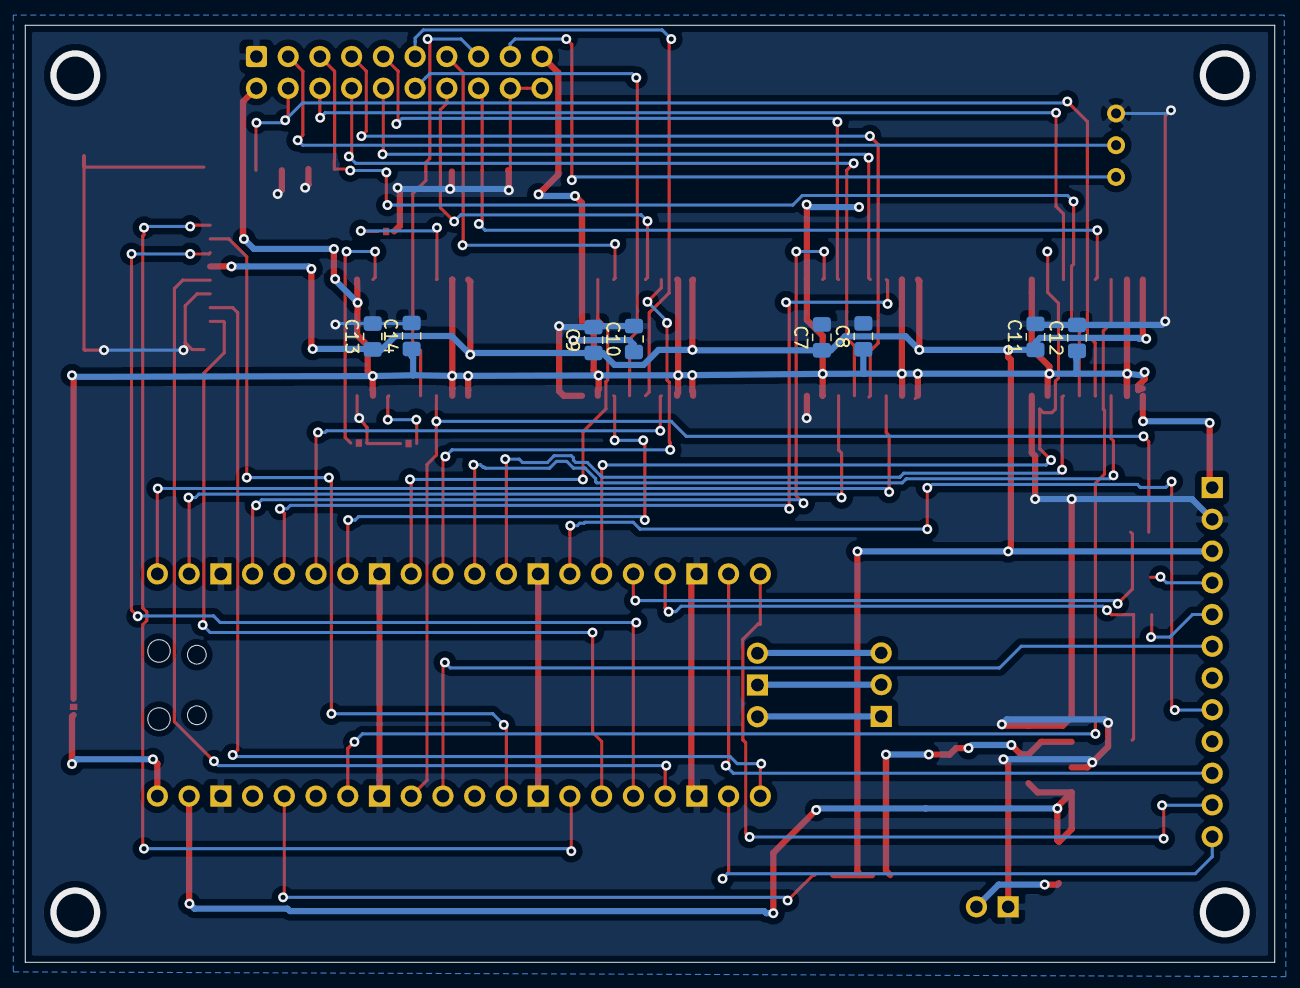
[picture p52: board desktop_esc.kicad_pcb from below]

Board: 2 copper layers, 100.0 x 75.0 mm, 37 parts (8 on the bottom side), 57 nets.

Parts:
C1, C2: 100nF; R_0805_2012Metric_Pad1.20x1.40mm_HandSolder
C3, C4, C5, C6: 150pF; C_0805_2012Metric_Pad1.18x1.45mm_HandSolder
C7: 100nGF; C_0805_2012Metric_Pad1.18x1.45mm_HandSolder
C8, C9, C10, C11, C12, C13, C14: 100nF; C_0805_2012Metric_Pad1.18x1.45mm_HandSolder
D5: SS36; D_SOD-123
J1: Conn_02x10_Odd_Even; IDC-Header_2x10_P2.54mm_Latch_Vertical
J2: Conn_01x12_Female; PinHeader_1x12_P2.54mm_Vertical
J3: Conn_01x03_Female; PinHeader_1x03_P2.54mm_Vertical
J7: Conn_01x02_Female; PinSocket_1x02_P2.54mm_Vertical
JP1: TOUCH_CS; SolderJumper-2_P1.3mm_Open_TrianglePad1.0x1.5mm
JP2: TOUCH_RX; SolderJumper-2_P1.3mm_Open_TrianglePad1.0x1.5mm
JP3: TOUCH_MISO; SolderJumper-2_P1.3mm_Open_TrianglePad1.0x1.5mm
JP4: TOUCH_TX; SolderJumper-2_P1.3mm_Open_TrianglePad1.0x1.5mm
JP5, JP6: Jumper_NO_Small; SolderJumper-2_P1.3mm_Open_TrianglePad1.0x1.5mm
JP7: 40109_B_GND; SolderJumper-2_P1.3mm_Bridged_RoundedPad1.0x1.5mm
JP8: 40109_C_GND; SolderJumper-2_P1.3mm_Bridged_RoundedPad1.0x1.5mm
JP9: 40109_D_GND; SolderJumper-2_P1.3mm_Bridged_RoundedPad1.0x1.5mm
JP10: Jumper_NC_Small; SolderJumper-2_P1.3mm_Bridged_RoundedPad1.0x1.5mm
RV1: 20k; Potentiometer_Bourns_3296W_Vertical
U1: Pico; RPi_Pico_SMD_TH
U2: AP1117-33; SOT-223-3_TabPin2
U3, U4, U5, U6: ajm_cd40109; SOIC-16W_7.5x10.3mm_P1.27mm
XS1: 502p_SD_ebay-uSD-push_push_SMD; Conn_uSDcard

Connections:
+3V3: C7.1, C9.1, C11.1, C13.1, J2.3, JP5.2, JP6.1, U3.16, U4.16, U5.16, U6.16, XS1.4
+5V: C8.1, C10.1, C12.1, C14.1, J1.2, J1.19, J2.1, JP10.1, U3.1, U3.2, U3.7, U3.9, U3.15, U4.1, U4.2, U4.7, U4.9, U4.15, U5.1, U5.2, U5.7, U5.9, U5.15, U6.1, U6.2, U6.7, U6.9, U6.15
A0_3V3: U1.15, U5.10
A0_5V: J1.6, U5.11
CS_N_3V3: JP1.1, U1.32, U6.3
CS_N_5V: C6.1, J1.15, U6.4
DB0_3V3: U1.1, U3.3
DB0_5V: J1.7, U3.4
DB1_3V3: U1.2, U3.6
DB1_5V: J1.8, U3.5
DB2_3V3: U1.4, U3.10
DB2_5V: J1.9, U3.11
DB3_3V3: U1.5, U3.14
DB3_5V: J1.10, U3.13
DB4_3V3: U1.6, U4.3
DB4_5V: J1.11, U4.4
DB5_3V3: U1.7, U4.6
DB5_5V: J1.12, U4.5
DB6_3V3: U1.9, U4.10
DB6_5V: J1.13, U4.11
DB7_3V3: U1.10, U4.14
DB7_5V: J1.14, U4.13
DBG_CLK_3V3: J2.11, U1.20
DBG_DATA_3V3: J2.10, U1.19
DRDY_3V3: J2.6, U1.31
GND: C1.2, C2.2, C3.2, C4.2, C5.2, C6.2, C7.2, C8.2, C9.2, C10.2, C11.2, C12.2, C13.2, C14.2, J1.1, J1.18, J1.20, J2.2, J7.1, JP7.2, JP8.2, JP9.2, RV1.3, U1.3, U1.8, U1.13, U1.18, U1.23, U1.28, U1.33, U1.38, U2.1, U3.8, U4.8, U5.8, U6.8, XS1.6
MISO_D0: U1.21, XS1.7
MOSI_DI: U1.25, XS1.3
unnamed: C2.1, JP5.1, U2.2
unnamed: D5.2, J7.2
unnamed: J1.3, RV1.2
unnamed: J1.17, RV1.1
unnamed: J3.1, U1.43
unnamed: J3.2, U1.42
unnamed: J3.3, U1.41
unnamed: JP6.2, U1.36
unnamed: JP7.1, U6.6
unnamed: JP8.1, U6.10
unnamed: JP9.1, U6.14
RD_N_3V3: U1.11, U5.3
RD_N_5V: C3.1, J1.4, U5.4
RESET_N_3V3: U1.34, U5.14
RESET_N_5V: C4.1, J1.16, U5.13
RX_3V3: J2.4, JP2.1
RX_CS_3V3: JP3.2, JP4.2, U1.17
SCK_3V3: J2.8, U1.14
SD_CLK: U1.24, XS1.5
SD_DAT1: U1.26, XS1.8
SD_DAT2: U1.27, XS1.1
SD_SS: U1.29, XS1.2
TX_3V3: J2.5, JP4.1
TX_RX_3V3: JP1.2, JP2.2, U1.16
VBUS: JP10.2, U1.40
VSYS: C1.1, D5.1, U1.39, U2.3
WR_N_3V3: U1.12, U5.6
WR_N_5V: C5.1, J1.5, U5.5
WS_3V3: J2.12, U1.22

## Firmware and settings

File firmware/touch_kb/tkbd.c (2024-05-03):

///////////////////////////////////////////////////////////////////////////////
//
// Experimental Schools Computer Simulator
//
////////////////////////////////////////////////////////////////////////////////
//
// Toouch Keyboard
//
// Runs on RP Pico
//
////////////////////////////////////////////////////////////////////////////////


#pragma GCC diagnostic ignored "-Wwrite-strings"

#include <ctype.h>
#include <math.h>
#include <stdarg.h>
#include <stdio.h>
#include <stdlib.h>
#include <string.h>

#include "pico/stdlib.h"
#include "hardware/pio.h"
#include "hardware/dma.h"
#include "hardware/irq.h"
#include "hardware/flash.h"
#include "hardware/structs/bus_ctrl.h"

#define DEBUG_STOP while(1) {}

// Some logic to analyse:
#include "hardware/structs/pwm.h"
#include "pico/multicore.h"
#include "pico/bootrom.h"

void set_gpio_output(int p)
{
  gpio_init(p);
  gpio_set_dir(p, GPIO_OUT);
}

void set_gpio_input(int p)
{
  gpio_init(p);
  gpio_set_dir(p, GPIO_IN);
}

int main(void)
{
  ////////////////////////////////////////////////////////////////////////////////
  //
  // Overclock as needed
  //
  ////////////////////////////////////////////////////////////////////////////////
  
#define OVERCLOCK 135000
  //#define OVERCLOCK 200000
  //#define OVERCLOCK 270000
  //#define OVERCLOCK 360000
  
#if OVERCLOCK > 270000
  /* Above this speed needs increased voltage */
  vreg_set_voltage(VREG_VOLTAGE_1_20);
  sleep_ms(1000);
#endif
  
  /* Overclock */
  set_sys_clock_khz( OVERCLOCK, 1 );

  stdio_init_all();

  sleep_ms(2000);

  printf("\n");
  printf("\n                                  ********************************************");
  printf("\n                                  * Experimental Schools Keyboard            *");
  printf("\n                                  ********************************************");
  printf("\n");


  ////////////////////////////////////////////////////////////////////////////////
  // Set up GPIOs
  
#define DRV 2
  
  gpio_init(DRV);
  gpio_set_dir(DRV, GPIO_OUT);

#if 0
  while(1)
    {
      gpio_put(DRV, 1);
      sleep_us(20);
      gpio_put(DRV, 0);
      sleep_us(5);
    }

#endif

////////////////////////////////////////////////////////////////////////////////
  
  // Induced voltage sensing
  
#if 0

  for(int j=10; j<12; j++)
    {
      gpio_init(j);
      gpio_set_dir(j, GPIO_IN);
      gpio_set_pulls (j, 0, 0);
    }
  
  int x[30];
  int g[30];

  for(int j=10; j<12; j++)
    {
      x[j] = 0;
      g[j] = 0;
    }
	
  while(1)
    {
      for(int j=10; j<12; j++)
	{
	  
	  g[j] = gpio_get(j);
	  
	  if( !g[j] )
	    {
	      if( x[j] > 0 )
		{
		  x[j]--;
		}
	    }
	  else
	    {
	      if( x[j] <100 )
		{
		  x[j]++;
		}
	      
	    }
	  

	}

      printf("\n");
      for(int j=10; j<12; j++)
	{
	  printf("%d    ", x[j]);
	}
    }
  
#endif


////////////////////////////////////////////////////////////////////////////////
//
// Shift register voltage sensing
//
////////////////////////////////////////////////////////////////////////////////

#if 1

////////////////////////////////////////////////////////////////////////////////
//
// Read an 8 bit value from a 165 latch
//
////////////////////////////////////////////////////////////////////////////////

#define PIN_SHLD    2
#define PIN_SCLKIN  3
#define PIN_SDAIN   4
#define PIN_SER     5
#define PIN_CLK_INH 6

uint8_t read_165(const uint latchpin)
{
  uint8_t value = 0;
  
  // Latch the data
  gpio_put(latchpin, 0);
  gpio_put(latchpin, 0);
  sleep_us(100);
  
  gpio_put(latchpin, 1);

  // Clock the data out of the latch
  for(int i=0; i<8; i++)
    {
      sleep_us(1);
      
      // Read data
      value <<= 1;
      if( gpio_get(PIN_SDAIN) )
	{
	  value |= 1;
	}

      sleep_us(1);
      gpio_put(PIN_SCLKIN, 0);
      sleep_us(1);
      gpio_put(PIN_SCLKIN, 1);


    }

#if XP_DEBUG  
  printxy_hex(0,3, value);
#endif
  return(value);
}

 set_gpio_output(PIN_SHLD);
 set_gpio_output(PIN_SCLKIN);
 set_gpio_input(PIN_SDAIN);
 set_gpio_input(PIN_SER);
 set_gpio_output(PIN_CLK_INH);



 
 int d = 0;
 gpio_put(PIN_CLK_INH, 0);
 
while(1)
  {
    d = read_165(PIN_SHLD);

    printf("\nD:%02X", d);
  }

#endif
}

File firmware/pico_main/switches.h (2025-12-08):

////////////////////////////////////////////////////////////////////////////////
//
// Switches
//
////////////////////////////////////////////////////////////////////////////////



//------------------------------------------------------------------------------
//
// All debug switches off or set up
#if 0
#define DEBUG_VERBOSE_TEST     0
#define DEBUG_STAGES           0
#define DEBUG_EXTRACODE        0
#define DEBUG_CALC_STATE       0
#define DEBUG_A_DECODE         0
#define DEBUG_LOOP             0
#define DEBUG_BCD_CORRECTION   0
#define DEBUG_SW_BCD_SUM       0
#define DEBUG_DW_BCD_SUM       0
#define DEBUG_REG_ASSIGN       0
#define DEBUG_FP               0
#define DEBUG_FP_SUMMARY       0
#define DEBUG_MSD_SHIFT        0
#define DEBUG_SW_SHIFT         0
#define DEBUG_BCD_TO_BINARY    0

#define DEBUG_TEST             0    // Test instruction
#define DEBUG_TEST_SEQ         0    // Test sequences

#define DEBUG_SERIAL           0
#define DEBUG_KEY_SCAN         0
#define DEBUG_ADDR_MODES       0
#define DEBUG_INST_21          0
#define DEBUG_INST_22          0

#define DEBUG_STOP             0
#define DEBUG_RESTART          0
#define DEBUG_EXECUTE          0
#define DEBUG_PREPARE          0
#define DEBUG_DISPLAY          0
#define DEBUG_DISPLAY_ON_LINE  0
#define DEBUG_BRANCH           0

#define DUMP_STATE_STAGE_C     0
#define DEBUG_REGISTER_ASSIGN  0

#define DEBUG_SUPPRESSED       0
#endif

// All debug switches off or set up
#if 1
#define DEBUG_VERBOSE_TEST     1
#define DEBUG_ENTRY            1
#define DEBUG_STAGES           1
#define DEBUG_EXTRACODE        1
#define DEBUG_CALC_STATE       1
#define DEBUG_A_DECODE         1
#define DEBUG_LOOP             0
#define DEBUG_BCD_CORRECTION   0
#define DEBUG_SW_BCD_SUM       1
#define DEBUG_DW_BCD_SUM       1
#define DEBUG_REG_ASSIGN       1
#define DEBUG_FP               1
#define DEBUG_FP_SUMMARY       1
#define DEBUG_MSD_SHIFT        1
#define DEBUG_SW_SHIFT         1
#define DEBUG_BCD_TO_BINARY    1

#define DEBUG_TEST             1    // Test instruction
#define DEBUG_TEST_SEQ         1    // Test sequences

#define DEBUG_SERIAL           1
#define DEBUG_KEY_SCAN         1
#define DEBUG_ADDR_MODES       1
#define DEBUG_INST_21          1
#define DEBUG_INST_22          1

#define DEBUG_RESTART          1
#define DEBUG_EXECUTE          0
#define DEBUG_PREPARE          1

#define DEBUG_DISPLAY          0
#define DEBUG_DISPLAY_SCREEN   1
#define DEBUG_DISPLAY_ON_LINE  0
#define DEBUG_BRANCH           1

#define DUMP_STATE_STAGE_C     1
#define DEBUG_REGISTER_ASSIGN  1
#define DEBUG_DISPLAY_IAR      1
#define DEBUG_FN_CALL          1
#define DEBUG_KEYS             1
#define DEBUG_NEXT_IAR         1
#define DEBUG_ENTER_EXTRACODE  1
#define DEBUG_LOAD_FROM_STORE  1
#define DEBUG_STAGE_DISPLAY    1
#define DEBUG_LOAD_IAR         1
#define DEBUG_SUPPRESSED       0
#endif

//------------------------------------------------------------------------------

#if 0

#define DEBUG_CALC_STATE       0
#define DEBUG_A_DECODE         0
#define DEBUG_LOOP             0
#define DEBUG_BCD_CORRECTION   0
#define DEBUG_SW_BCD_SUM       0
#define DEBUG_DW_BCD_SUM       0
#define DEBUG_REG_ASSIGN       0
#define DEBUG_FP               1
#define DEBUG_FP_SUMMARY       1
#define DEBUG_MSD_SHIFT        1
#define DEBUG_SW_SHIFT         1
#define DEBUG_BCD_TO_BINARY    1

#define DEBUG_TEST             0    // Test instruction
#define DEBUG_TEST_SEQ         0    // Test sequences

#define DEBUG_SERIAL           0
#define DEBUG_KEY_SCAN         0
#define DEBUG_ADDR_MODES       0
#define DEBUG_INST_21          0
#define DEBUG_INST_22          0

#define DEBUG_DISPLAY          0
#define DEBUG_DISPLAY_ON_LINE  0

#define DEBUG_RESTART          0
#define DEBUG_EXECUTE          0
#define DEBUG_PREPARE          1
#define DEBUG_BRANCH           1

#define DUMP_STATE_STAGE_C     1
#define DEBUG_REGISTER_ASSIGN  1
#endif

////////////////////////////////////////////////////////////////////////////////
//
// Main types of firmware
//
// SMALL:
// This firmware for a small PCB that has a 0.96" OLED display, a keyboard
// made form tactile switches and an SD catrd slot. There are some headers
// for unused GPIOs.
//
// DESKTOP:
// This is a PCB which has a Pico, a voltage regulator and circuitry to
// drive a capacitive touch keyboard and a large LCD screen. There is no
// keyboard or display on this PCB.

#define ESC_TYPE_SMALL         1
#define ESC_TYPE_DESKTOP       0

#define ESC_KBD_VOLT_TOUCH     0
#define ESC_KBD_QT             1

// Implement the extracode framework as instruction sin 100..199
// Otherwise coded instructions.
#define EXTRACODE_FRAMEWORK    1

// Suppressed output has no leading zeros and no + sign.
// This is closer to the original machine.

#define SUPPRESSED_OUTPUT      1
#define OLED_ON                1
#define SD_ON                  1
#define ERRORS_ON              0
#define WARNINGS_ON            0

// Original type display layout. Wider character areas, and decimal point
// squashed between characters
#define ORIGINAL_CHARACTERS    1

// Modern font is stabdard 5x7 font. Not modern is the original font.
#define MODERN_FONT            0
#define FONT_WIDTH             8

#define PIXEL_SCALE  3
#define PIXEL_SCALE2 2

//------------------------------------------------------------------------------
//
// Execution flow debug
//


#if DEBUG_ENTRY
#define FN_ENTRY         printf("\n>>>>>>>>>>>>>>>>>>>>>>>>>>>>>>>>>>>>>>>>>>>>>>>>>>>>>>>>>>>>>>>>>>>>>>>>>>>>>>>>%s\n", __FUNCTION__)
#define FN_ENTRY_DISPLAY printf("\n>>>>>>>>>>>>>>>>>>>>>>>>>>>>>>>>>>>>>>>>>>>>>>>>>>>>>>>>>>>>>>>>>>>>>>>>>>>>>>>>%s display:%d\n", __FUNCTION__, display)
#define FN_EXIT          printf("\n<<<<<<<<<<<<<<<<<<<<<<<<<<<<<<<<<<<<<<<<<<<<<<<<<<<<<<<<<<<<<<<<<<<<<<<<<<<<<<<<%s\n", __FUNCTION__)
#else
#define FN_ENTRY_DISPLAY
#define FN_ENTRY
#define FN_EXIT
#endif

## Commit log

2023-12-19 Can run two instructions but only stage a and stage b, manually.
2023-12-21 Addition now bcd normalised correctly
    [switches.h]
2023-12-22 Added integer arithmetic (signed, digits) registers use this for calculations. Overflow is there, but does that make sense? If it's there then how is nine or tens complement coded? Is only floating p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
    [switches.h]
2023-12-23 Added small PCB. Small keyswitches and small OLED display. headers for connection to other KB and display hardware. SD card slot.
    [file6589DD6E.sch, file6589ED5F.sch, file658A0FE7.sch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]
2023-12-24 Added PCB artwork for V1.0 small PCb version. Pico, small keyboard and a 0.96" OLED screen. Options for mounting screen and powering the board. GPIOs run to connectors so external keyboard and displa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
    [small_esc-B_Cu.gbr, small_esc-B_Mask.gbr, small_esc-B_Paste.gbr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]
2023-12-27 Added fonts for html display. Made ESC font.
2024-01-05 Added support for 0.96" oled display on the PCB version of the Schools Computer
2024-01-09 SD card .esc file read and write now working. Ony one file used: 'state.esc'
2024-04-09 Added floating point multiply as C code. Written in a way that allows it to be re-written in ESC instructions as an extracode.
2024-04-11 Tidied error messages, separate flag for instructions to update display
    [switches.h]
2024-04-13 alculates sin(x) for small x. The input instruction (78) is not working for some reason. Put x in the code in the test sequence setup
    [switches.h]
2024-05-07 Fixed instruction 78,and maybe others that stop. Run now cycles through stages A,B and C instead of running to C repeatedly so that checking of the stop flag can be done at each stage. Instruction 78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
    [#esc_case.dxf, esc_case.dxf]
2024-06-18 QT Touch keyboard is working. The QT IC needs to have the setup programmed into the eeprom/flash with the Q menu W option, then calibrate with L and C. The setups seem to them be fine for the keyboar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
2025-11-13 FP multiplyu now works. A sign problem, where there was no sign (0 nibble) in the sign position of one of the arguments. Was interpreted as 'different signs'
    [switches.h]
2025-11-13 Update README with extracode framework and fixes
    Added framework details for executing extracode and corrected typos.
2025-11-15 Added display of the A,B and C stages of the extracode execution. It involves a flag to indicate extracode exit and also using the auxiliary IAR instead of the IAR for the decode display. This should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
2025-11-16 Fixed some formatting in instruction displays Fixing the single address input instructions Moved the update after inout flag actuion to stage C from execute, so it function on RUN and C
    [switches.h]
2025-11-16 Working on fix to RUN of extracodes and the 79 stop and disoplay X,Y,Z instruction.
    [switches.h]
2025-11-17 Fixed extracode stepping and running. Tidied display Clear keyboard register after entry of value
    [switches.h]
2025-11-23 Moved execution of instructions to stage C, as original machine did. Stopping for entry of a value should be done in stage B, though
2025-11-24 Extracodes can now be run it appears. Display is not quite correct but that can be fixed later.
    [switches.h]
2025-11-30 Fixed problem with bounding addresses in the BOUND_ADDRESS macro. Other fixes in indirect addressing single address instructions.
    [switches.h]
2025-12-02 Fixed RH6 instructions 14cd Now preserves the non-RH6 digits.
    [switches.h]
2025-12-04 Adjusted the decimal point to match the original. Adjusted the font to match the original. Decimal poiint still noit correct, as character positions seem to be adjusted to make space for the point. S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
    [switches.h]
2025-12-07 Tidied and compacted the status dump. Trying to limit the trace length. Adding nmore register instruction tests.
